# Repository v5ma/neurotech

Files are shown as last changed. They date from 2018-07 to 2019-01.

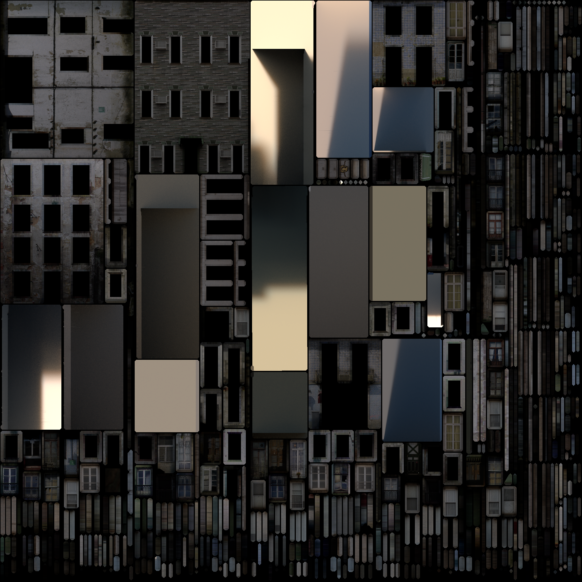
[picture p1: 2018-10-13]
brainduino-server/assets/Postwarcity/textures/TexturesCom_BuildingsTallHouse0057_S_diffuse.png

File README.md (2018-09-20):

Wiki
====

https://www.noisebridge.net/wiki/DreamTeam/Brainduinov2

Commands
========

Commands are sent by write ASCII characters to the bluetooth serial device. The brainduino echos back the lower-case compliment of the command sent 15 times followed by a return carridge. For example:

```
Client writes 'S' to bluetooth serial device
If the command is recieved by the brainduino, the brainduino writes 'sssssssssssssss' + '\r' back over bluetooth

```
ASCII | Result
---   | ---
I     | Bypass the MAX7480 (8th-order butterworth filter)
P     | Set 200HZ low-pass corner frequency of MAX7480 (8th-order butterworth filter)
O     | Set 150HZ low-pass corner frequency of MAX7480 (8th-order butterworth filter)
Q     | Set 100HZ low-pass corner frequency of MAX7480 (8th-order butterworth filter)
Z     | Set 50HZ low-pass corner frequency of MAX7480 (8th-order butterworth filter)
M     | Set 40HZ low-pass corner frequency of MAX7480 (8th-order butterworth filter)
S     | Set 32HZ low-pass corner frequency of MAX7480 (8th-order butterworth filter)
V     | Set sample rate to 500HZ
W     | Set sample rate to 250HZ
B     | Set sample rate to 190HZ
A     | Impedance check on with +1ch
T     | Impedance check on with -1ch
C     | Impedance check on with +2ch
D     | Impedance check on with -2ch
E     | Impedance check off
F     | Generate test signal with frequency = 12HZ
G     | Generate test signal with frequency = 28HZ
H     | Generate test signal with frequency = 111HZ
J     | Generate test signal with power = 0.1
K     | Generate test signal with power = 1
Y     | Set 4 channel mode
X     | Set 2 channel mode with 500HZ sample rate
U     | Set 2 channel mode with 250HZ sample rate

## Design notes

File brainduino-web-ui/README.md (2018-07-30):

On Collaboration Station
========================
In a terminal
```
$ source ~/pyvenv/brainduino/bin/activate
$ cd ~/brainduino/brainduino-web-ui
$ sudo env "PATH=$PATH" python main.py
```
Navigate to file:///home/noisebridge/brainduino/brainduino-web-ui/ws.html in a web browser. The current version of our ws.js (our simple Javascript) logs the brainduino data sent over the websocket to the browser console.

Setup
=====
* Requires Python 3.5+
* Depends on websockets and pyserial libraries

Setup for EEG reading instrument
Steps to recreate variance with 3d modeling a-frame: 
 - Connect to Bluetooth
 - run main.py
 - run web page file:///home/noisebridge/brainduino/brainduino-web-ui/webxr1.html

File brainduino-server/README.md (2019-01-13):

Operating instructions
======================

Update code
```
cd ~/go/src/github.com/Micah1/neurotech/
git pull origin master
dep ensure
```

Build and run webserver
```
cd ~/go/src/github.com/Micah1/neurotech/brainduino-server/webserver
go build
sudo ./webserver -addr 10.20.7.127:80
```

Build and run Brainduino
```
cd ~/go/src/github.com/Micah1/neurotech/brainduino-server/brainduino
go build
sudo ./brainduino -addr 10.20.7.127:80 # alternatively sudo ./brainduino --url ml.sensorium.space
```

index.html location
`~/go/src/github.com/Micah1/neurotech/brainduino-server/webserver/static/views/index.html`

load in browser
`http://10.20.7.127:80`

To commit changes to github at the end of the night
```
git add . --all
git commit -m "<what's in the commit>"
git push origin master
```

To inspect changes before committing try running `git status` or `git log`

Event Schema
============
```
type Sample struct {
        Name           string
        Channels       []float64
        Timestamp      time.Time
        SequenceNumber uint
}
Example websocket event JSON:
{
  "data": {
    "Name": "sample",
    "Channels": [0.01, 0.32],
    "Timestamp": "2018-10-10T21:05:05.031850444-07:00",
    "SequenceNumber": 1
  }
}

type FFTData struct {
        Name           string
        Channels       [][]float64
        Timestamp      time.Time
        SequenceNumber uint
}
Example websocket event JSON:
{
  "data": {
    "Name": "fft",
    "Channels": [[0.01, 0.32, ..., 0.123], [0.09234, 0.1234123, ..., 0.123543]],
    "Timestamp": "2018-10-10T21:05:05.031850444-07:00",
    "SequenceNumber": 1
  }
}
```

Online Instructions
===================
If the webserver errors out you can run sudo ifconfig to make sure the network broadcast port hasn't changed. It was once 10.20.1.164:80, and I think a new router installed at noise bridge caused it to change to 10.20.7.127

A copy of the webserver code runs on ml.sensorium.space.

For details see `./brainduino --help` or `./webserver --help`

All files in `~/go/src/github.com/Micah1/neurotech/brainduino-server/webserver/static/views` are served upon request by the brainduino-server program. For example, when the browser issues the following request `GET localhost:8080/static/index.html`, brainduino-server will serve the index.html file. `GET localhost:8080` does the same thing. `GET localhost:8080/chartsngraphs` is equivalent to `GET localhost:8080/static/chartsngraphs.html`.

For writting commands to the braindunio try `POST localhost:8080/command/S`. For a full list of brainduino commands see https://github.com/Micah1/neurotech.

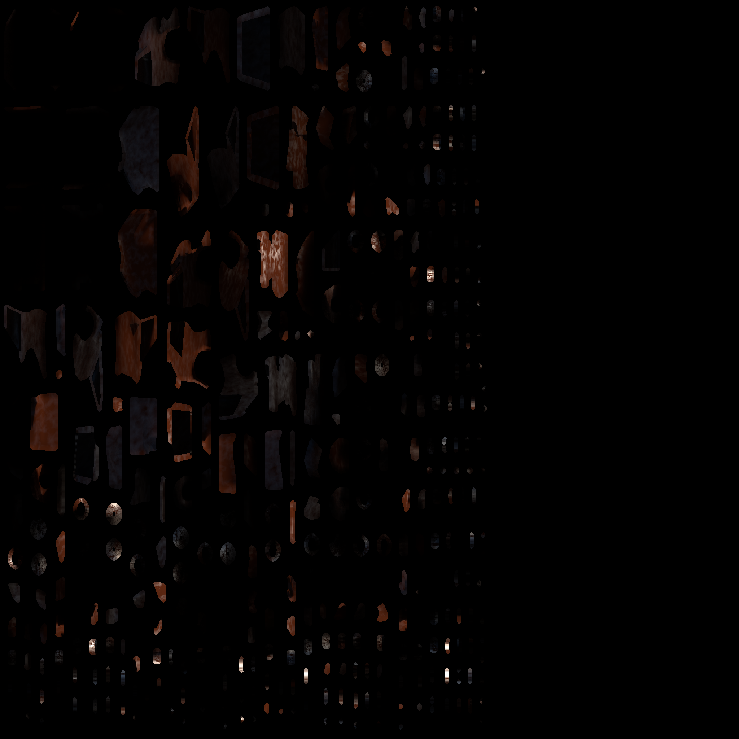
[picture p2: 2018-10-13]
brainduino-server/assets/Postwarcity/textures/jante.001_specularGlossiness.png

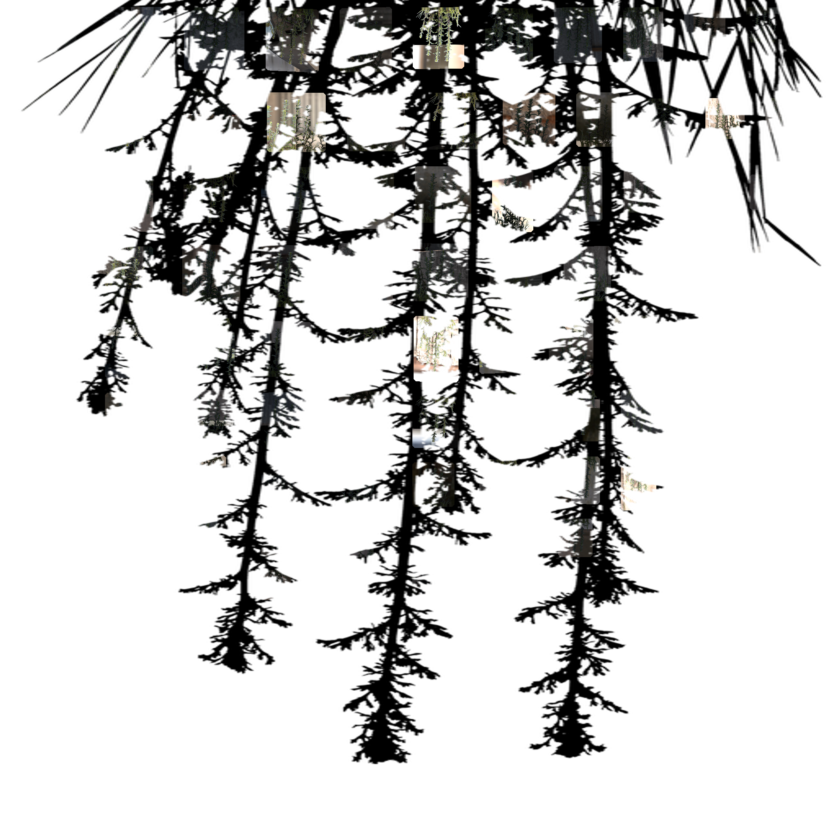
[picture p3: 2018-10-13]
brainduino-server/assets/Postwarcity/textures/TexturesCom_NaturePlants0005_1_alphamasked_S_diffuse.png

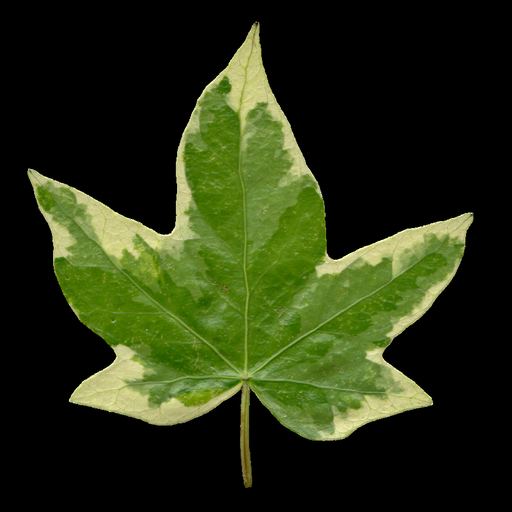
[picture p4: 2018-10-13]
brainduino-server/assets/Postwarcity/textures/ivy-leaves.001_emissive.png

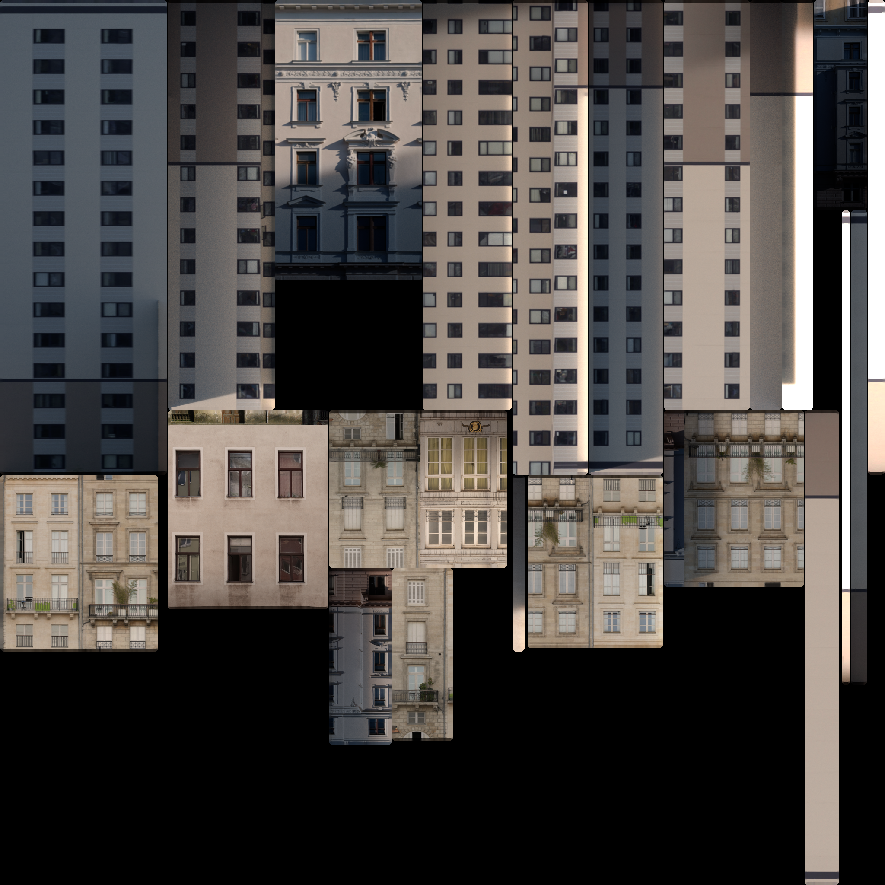
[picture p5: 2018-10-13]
brainduino-server/assets/Postwarcity/textures/wall.buidings.001_diffuse.png

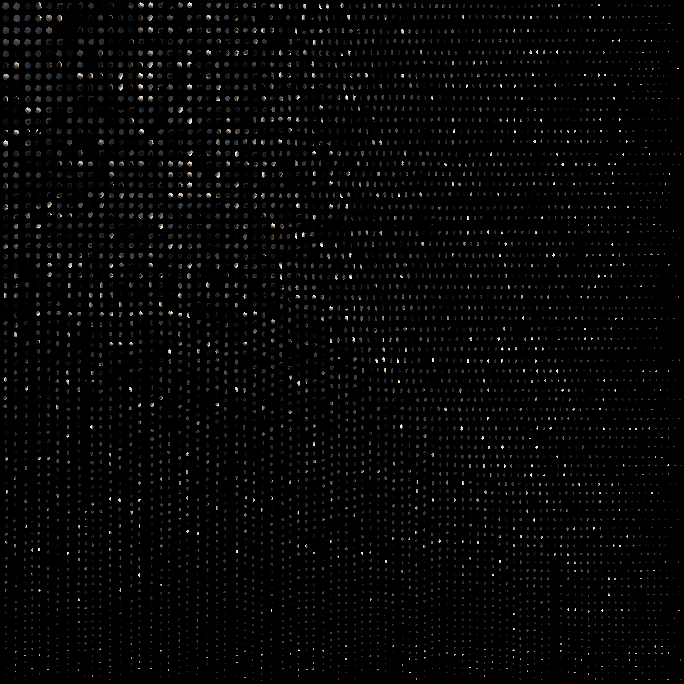
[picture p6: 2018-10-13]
brainduino-server/assets/Postwarcity/textures/gravas_diffuse.png

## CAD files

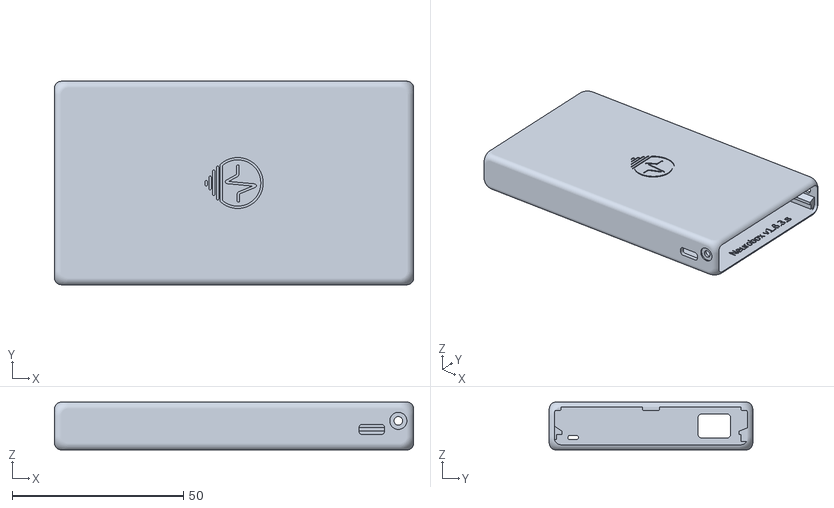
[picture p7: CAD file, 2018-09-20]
brainduino-case/Neurobox16b3s.stl
104.9 x 59.5 x 14.0

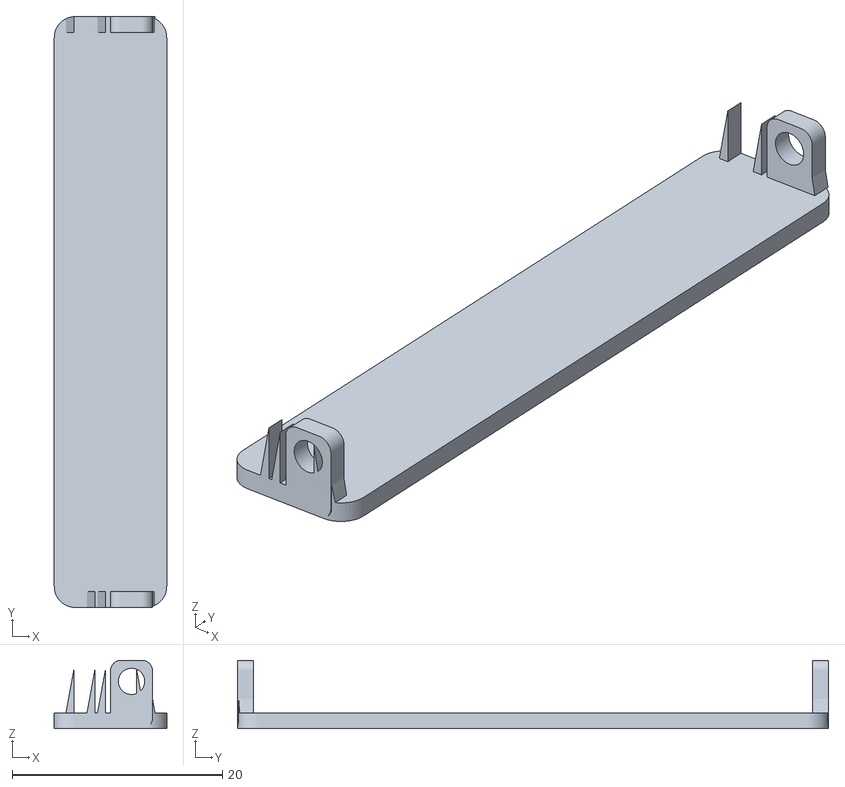
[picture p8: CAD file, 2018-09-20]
brainduino-case/Neurobox16b4s2.stl
10.7 x 56.2 x 6.50

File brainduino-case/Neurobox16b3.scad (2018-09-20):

/* [Credits] */
// www.brain-duino.com
// License CC-BY-SA 4.0
// Silver Kuusik - silver.kuusik@gmail.com

// Big thanks to:
// FB Aka Heartman/Hearty 2016
// http://www.thingiverse.com/thing:1264391

// Big thanks to:
// R. Miloh Alexander
// froggytoad@gmail.com

// Big thanks to:
// beau@nubcore.com
// 3D printing


/* [Version info] */
Version = "Neurobox v1.6.3.s";

/* [Box dimensions] */
// length, total, includes wall thickness
Length = 105;
// width, total, includes wall thickness
Width = 59.5;
// height, total includes wall thickness
Height = 14.0; // 23.5; -->> 15.5 -->> 14.0
// wall thickness
Thick = 1.5; // [2:5]

// diference 1.6 -->> 1.6.s
deltaH = 7.5; 

/* [Box options] */
// filet diameter
Filet = 2; // [0.1:12]
// filet smoothness
Resolution = 50; // [1:100]

module prism(l, w, h) {
    polyhedron(
       points=[[0,0,0], [l,0,0], [l,w,0], [0,w,0], [0,w,h], [l,w,h]],
       faces=[[0,1,2,3],[5,4,3,2],[0,4,5,1],[0,3,4],[5,2,1]]
    );
}

// round_box module
module round_box($l=Length, $w=Width, $h=Height) {
    $fn=Resolution;
    translate([0, Filet, Filet]) {
        minkowski() {
            cube([$l-(Filet/2), $w-(2*Filet), $h-(2*Filet)]);
            rotate([0, 90, 0]) {
                cylinder(r=Filet);
            }
            rotate([0, 0, 90]) {
                cylinder(r=Filet);
            }
            rotate([90, 0, 0]) {
                cylinder(r=Filet);
            }
        }
    }
} // end of round_box module

// box module
module box() {
    $fn=Resolution;
    // assemble box and it's holes
    difference() {
        // make a rounded box
        translate([Filet+2, Filet+1, Filet]) {
            round_box(Length-8, Width-5, Height-5);
        }
        // make the rounded box empty inside
        translate([Thick, Thick, Thick]) {
            translate([0, 0, 0]) {
                minkowski() {
                    cube([Length-3, Width-3, Height-3]);
                }
            }
            // make the rear opening corners round
             translate([Length-3.5, 2, 2]) {
                 minkowski() {
                    cube([1, Width-7, Height-7]);
                     rotate([0, 90, 0]) {
                        cylinder(r=Filet);
                    }
                  }
            }
        }
        // version on the rear opening
        translate([Length-3.5, Width/4, Thick-0.3]) {
            rotate([0, 0, 90]) {
                color("RoyalBlue")
                linear_extrude(0.4) {
                    text(text=Version, size=3);
                }
            }
        }
        // logo substracted from bottom part
        mirror([0, 1, 0]) {
            rotate([0, 0, -90]) {
                translate([Width/2+1, 12, 0]) {
                    logo2(0.3);
                }
            }
        }
        // logo substracted from top part
        rotate([180, 0, 0]) {
            translate([Length/2, -Width/2, -Height]) {
                rotate([0, 0, -90]) {
                    mirror([1, 0, 0]) {
                        logo(0.3);
                    }
                }
            }
        }
        // lower left lid fixation screw head hole
        translate([Length-4.5, 0.5, 8.5]) {
            rotate([90, 0, 0]) {
                cylinder(d=5);
            }
        }
        // lower left lid fixation screw hole
        translate([Length-4.5, 2, 8.5]) {
            rotate([90, 0, 0]) {
                cylinder(d=2.5, 3);
            }
        }
        /*
        // upper left lid fixation screw head hole
         translate([Length-4.5, 0.5, Height-5.5]) {
             rotate([90, 0, 0]) {
                 cylinder(d=5);
            }
         }
        // upper left lid fixation screw hole
        translate([Length-4.5, 2, Height-5.5]) {
            rotate([90, 0, 0]) {
                cylinder(d=2.5, 3);
            }
        }
        */
        /*
        // lower right lid fixation screw head hole
        translate([Length-4.5, Width+0.5, 5.5]) {
            rotate([90, 0, 0]) {
                cylinder(d=5);
            }
        }
        // lower right lid fixation screw hole
        translate([Length-4.5, Width+1, 5.5]) {
            rotate([90, 0, 0]) {
                cylinder(d=2.5, 3);
            }
        }
        */
        // upper right lid fixation screw head hole   // Height-5.5 -->> 8.5
        translate([Length-4.5, Width+0.5, 8.5]) {
            rotate([90, 0, 0]) {
                cylinder(d=5);
            }
        }
        // upper right lid fixation screw hole   // Height-5.5 -->> 8.5
        translate([Length-4.5, Width+1, 8.5]) {
            rotate([90, 0, 0]) {
                cylinder(d=2.5, 3);
            }
        }
        // DC/DC usb charging hole // Length-19.25 -->> Length-14.25 -->> 15.0
        translate([Length-15.0, 2, 5.5]) {
            rotate([90, 0, 0]) {
                minkowski() {
                    cylinder(d=Filet);
                    cube([5.5, 1, 1]);
                }
            }
        }
        // headpad hole // Width-14.3 -->> 15.0,  12.75 -->> 4.5
        translate([-0.1, Width-15.0, 4.5]) {
            minkowski() {
                cube([1, 7.5, 5]);
                rotate([0, 90, 0]) {
                    cylinder(d=Filet, 3);
                }
            }
        }
        // 200Hz LED hole  12.5 -->> 4.0 -->> 3.5
        translate([-0.1, 6, 3.5]) {
            minkowski() {
                cube([1, 2, 0.25]);
                rotate([0, 90, 0]) {
                    cylinder(d=Filet/2, 3);
                }
            }
        }
        // button hole  -->> no need for s
        /*
         translate([0.5, 3, 3.25]) {
             sphere(r=7);
         }
        // canal for button
         translate([4.25, 1, 3.5]) {
             minkowski() {
                 cube([8.5, 1, 3]);
                 rotate([90, 0, 0]) {
                    cylinder(d=Filet*2);
                }
            }
        }
        */
    } // end of difference holes
    /*difference() {
        // button support cube
        translate([1.5, 1.5, 1.5]) {
            cube([6, 9, 8.75]);
        }
        // button hole
        translate([1.49, 5, 6]) {
            //sphere(r=10);
            rotate([0, 90, 0]) {
                cylinder(d=7, 7);
            }
        }
        // button sphere
        translate([0.5, 3, 3.25]) {
            sphere(r=7);
        }
    }*/
    // left upper PCB holding rail
    translate([1.5, 1.5, 12-deltaH]) {
        cube([Length-3-20, 2.25, 1]);
        translate([0, 0, 2.5]) {
            rotate([-90, 0, 0]) {
                prism(Length-3-20, 1.5, 2.25);
            }
        }
    }
    // left middle PCB psuher
    translate([1.5, 1.5, 10.5-deltaH]) {
        cube([Length-3-20, 0.6, 1.5]);
    }
    // right upper pcb holding rail
    translate([1.5, Width-4, 12-deltaH]) {
        cube([Length-3, 3, 1]);
        translate([0, 0, 1]) {
            prism(Length-3, 2.5, 1);
        }
    }
    // right middle pcb holding rail
    translate([1.5, Width-3.5, 10-deltaH]) {
        cube([Length-3, 2, 2]);
    }
    // right lower PCB holding rail
    /*translate([1.5, Width-4, 9.25]) {
        cube([Length-3, 3, 1]);
        translate([0, 2.5, -1]) {
            rotate([90, 0, 0]) {
                prism(Length-3, 1, 2.5);
            }
        }
    }*/
    // upper middle lid support
    translate([Length-2.8, Width/2-2, Height-2]) {
        minkowski() {
            cube([0.25, 4, 1]);
            rotate([0, 90, 0]) {
                cylinder(d=1, 1);
            }
        }
        translate([0, 4, 0]) {
            rotate([90, 0, -90]) {
                minkowski() {
                    prism(4, 1, 1);
                    rotate([0, 180, 0]) {
                        cylinder(d=1, 0.01);
                    }
                }
            }
        }
    }
    // upper left lid support
    translate([Length-2.8, 2, Height-2]) {
        minkowski() {
            cube([0.25, 1, 1]);
            rotate([0, 90, 0]) {
                cylinder(d=1, 1);
            }
        }
        translate([0, 1, 0]) {
            rotate([90, 0, -90]) {
                minkowski() {
                    prism(1, 1, 1);
                    rotate([0, 180, 0]) {
                        cylinder(d=1, 0.01);
                    }
                }
            }
        }
    }
    // upper right lid support
    translate([Length-2.8, Width-3, Height-2]) {
        minkowski() {
            cube([0.25, 1, 1]);
            rotate([0, 90, 0]) {
                cylinder(d=1, 1);
            }
        }
        translate([0, 1, 0]) {
            rotate([90, 0, -90]) {
                minkowski() {
                    prism(1, 1, 1);
                    rotate([0, 180, 0]) {
                        cylinder(d=1, 0.01);
                    }
                }
            }
        }
    }
    // lower right lid support
    /*
    translate([Length-2.8, Width-3, 1]) {
        minkowski() {
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

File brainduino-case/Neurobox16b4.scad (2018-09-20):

/* [Credits] */
// www.brain-duino.com
// License CC-BY-SA 4.0
// Silver Kuusik - silver.kuusik@gmail.com

// Big thanks to:
// FB Aka Heartman/Hearty 2016
// http://www.thingiverse.com/thing:1264391

// Big thanks to:
// R. Miloh Alexander
// froggytoad@gmail.com

// Big thanks to:
// beau@nubcore.com
// 3D printing


/* [Version info] */
Version = "Neurobox v1.6.3.s";

/* [Box dimensions] */
// length, total, includes wall thickness
Length = 105;
// width, total, includes wall thickness
Width = 59.5;
// height, total includes wall thickness
Height = 14.0; // 23.5; -->> 15.5 -->> 14.0
// wall thickness
Thick = 1.5; // [2:5]

// diference 1.6 -->> 1.6.s
deltaH = 7.5; 

/* [Box options] */
// filet diameter
Filet = 2; // [0.1:12]
// filet smoothness
Resolution = 50; // [1:100]

module prism(l, w, h) {
    polyhedron(
       points=[[0,0,0], [l,0,0], [l,w,0], [0,w,0], [0,w,h], [l,w,h]],
       faces=[[0,1,2,3],[5,4,3,2],[0,4,5,1],[0,3,4],[5,2,1]]
    );
}

// round_box module
module round_box($l=Length, $w=Width, $h=Height) {
    $fn=Resolution;
    translate([0, Filet, Filet]) {
        minkowski() {
            cube([$l-(Filet/2), $w-(2*Filet), $h-(2*Filet)]);
            rotate([0, 90, 0]) {
                cylinder(r=Filet);
            }
            rotate([0, 0, 90]) {
                cylinder(r=Filet);
            }
            rotate([90, 0, 0]) {
                cylinder(r=Filet);
            }
        }
    }
} // end of round_box module

// box module
module box() {
    $fn=Resolution;
    // assemble box and it's holes
    difference() {
        // make a rounded box
        translate([Filet+2, Filet+1, Filet]) {
            round_box(Length-8, Width-5, Height-5);
        }
        // make the rounded box empty inside
        translate([Thick, Thick, Thick]) {
            translate([0, 0, 0]) {
                minkowski() {
                    cube([Length-3, Width-3, Height-3]);
                }
            }
            // make the rear opening corners round
             translate([Length-3.5, 2, 2]) {
                 minkowski() {
                    cube([1, Width-7, Height-7]);
                     rotate([0, 90, 0]) {
                        cylinder(r=Filet);
                    }
                  }
            }
        }
        // version on the rear opening
        translate([Length-3.5, Width/4, Thick-0.3]) {
            rotate([0, 0, 90]) {
                color("RoyalBlue")
                linear_extrude(0.4) {
                    text(text=Version, size=3);
                }
            }
        }
        // logo substracted from bottom part
        mirror([0, 1, 0]) {
            rotate([0, 0, -90]) {
                translate([Width/2+1, 12, 0]) {
                    logo2(0.3);
                }
            }
        }
        // logo substracted from top part
        rotate([180, 0, 0]) {
            translate([Length/2, -Width/2, -Height]) {
                rotate([0, 0, -90]) {
                    mirror([1, 0, 0]) {
                        logo(0.3);
                    }
                }
            }
        }
        // lower left lid fixation screw head hole
        translate([Length-4.5, 0.5, 8.5]) {
            rotate([90, 0, 0]) {
                cylinder(d=5);
            }
        }
        // lower left lid fixation screw hole
        translate([Length-4.5, 2, 8.5]) {
            rotate([90, 0, 0]) {
                cylinder(d=2.5, 3);
            }
        }
        /*
        // upper left lid fixation screw head hole
         translate([Length-4.5, 0.5, Height-5.5]) {
             rotate([90, 0, 0]) {
                 cylinder(d=5);
            }
         }
        // upper left lid fixation screw hole
        translate([Length-4.5, 2, Height-5.5]) {
            rotate([90, 0, 0]) {
                cylinder(d=2.5, 3);
            }
        }
        */
        /*
        // lower right lid fixation screw head hole
        translate([Length-4.5, Width+0.5, 5.5]) {
            rotate([90, 0, 0]) {
                cylinder(d=5);
            }
        }
        // lower right lid fixation screw hole
        translate([Length-4.5, Width+1, 5.5]) {
            rotate([90, 0, 0]) {
                cylinder(d=2.5, 3);
            }
        }
        */
        // upper right lid fixation screw head hole   // Height-5.5 -->> 8.5
        translate([Length-4.5, Width+0.5, 8.5]) {
            rotate([90, 0, 0]) {
                cylinder(d=5);
            }
        }
        // upper right lid fixation screw hole   // Height-5.5 -->> 8.5
        translate([Length-4.5, Width+1, 8.5]) {
            rotate([90, 0, 0]) {
                cylinder(d=2.5, 3);
            }
        }
        // DC/DC usb charging hole // Length-19.25 -->> Length-14.25 -->> 15.0
        translate([Length-15.0, 2, 5.5]) {
            rotate([90, 0, 0]) {
                minkowski() {
                    cylinder(d=Filet);
                    cube([5.5, 1, 1]);
                }
            }
        }
        // headpad hole // Width-14.3 -->> 15.0,  12.75 -->> 4.5
        translate([-0.1, Width-15.0, 4.5]) {
            minkowski() {
                cube([1, 7.5, 5]);
                rotate([0, 90, 0]) {
                    cylinder(d=Filet, 3);
                }
            }
        }
        // 200Hz LED hole  12.5 -->> 4.0 -->> 3.5
        translate([-0.1, 6, 3.5]) {
            minkowski() {
                cube([1, 2, 0.25]);
                rotate([0, 90, 0]) {
                    cylinder(d=Filet/2, 3);
                }
            }
        }
        // button hole  -->> no need for s
        /*
         translate([0.5, 3, 3.25]) {
             sphere(r=7);
         }
        // canal for button
         translate([4.25, 1, 3.5]) {
             minkowski() {
                 cube([8.5, 1, 3]);
                 rotate([90, 0, 0]) {
                    cylinder(d=Filet*2);
                }
            }
        }
        */
    } // end of difference holes
    /*difference() {
        // button support cube
        translate([1.5, 1.5, 1.5]) {
            cube([6, 9, 8.75]);
        }
        // button hole
        translate([1.49, 5, 6]) {
            //sphere(r=10);
            rotate([0, 90, 0]) {
                cylinder(d=7, 7);
            }
        }
        // button sphere
        translate([0.5, 3, 3.25]) {
            sphere(r=7);
        }
    }*/
    // left upper PCB holding rail
    translate([1.5, 1.5, 12-deltaH]) {
        cube([Length-3-20, 2.25, 1]);
        translate([0, 0, 2.5]) {
            rotate([-90, 0, 0]) {
                prism(Length-3-20, 1.5, 2.25);
            }
        }
    }
    // left middle PCB psuher
    translate([1.5, 1.5, 10.5-deltaH]) {
        cube([Length-3-20, 0.6, 1.5]);
    }
    // right upper pcb holding rail
    translate([1.5, Width-4, 12-deltaH]) {
        cube([Length-3, 3, 1]);
        translate([0, 0, 1]) {
            prism(Length-3, 2.5, 1);
        }
    }
    // right middle pcb holding rail
    translate([1.5, Width-3.5, 10-deltaH]) {
        cube([Length-3, 2, 2]);
    }
    // right lower PCB holding rail
    /*translate([1.5, Width-4, 9.25]) {
        cube([Length-3, 3, 1]);
        translate([0, 2.5, -1]) {
            rotate([90, 0, 0]) {
                prism(Length-3, 1, 2.5);
            }
        }
    }*/
    // upper middle lid support
    translate([Length-2.8, Width/2-2, Height-2]) {
        minkowski() {
            cube([0.25, 4, 1]);
            rotate([0, 90, 0]) {
                cylinder(d=1, 1);
            }
        }
        translate([0, 4, 0]) {
            rotate([90, 0, -90]) {
                minkowski() {
                    prism(4, 1, 1);
                    rotate([0, 180, 0]) {
                        cylinder(d=1, 0.01);
                    }
                }
            }
        }
    }
    // upper left lid support
    translate([Length-2.8, 2, Height-2]) {
        minkowski() {
            cube([0.25, 1, 1]);
            rotate([0, 90, 0]) {
                cylinder(d=1, 1);
            }
        }
        translate([0, 1, 0]) {
            rotate([90, 0, -90]) {
                minkowski() {
                    prism(1, 1, 1);
                    rotate([0, 180, 0]) {
                        cylinder(d=1, 0.01);
                    }
                }
            }
        }
    }
    // upper right lid support
    translate([Length-2.8, Width-3, Height-2]) {
        minkowski() {
            cube([0.25, 1, 1]);
            rotate([0, 90, 0]) {
                cylinder(d=1, 1);
            }
        }
        translate([0, 1, 0]) {
            rotate([90, 0, -90]) {
                minkowski() {
                    prism(1, 1, 1);
                    rotate([0, 180, 0]) {
                        cylinder(d=1, 0.01);
                    }
                }
            }
        }
    }
    // lower right lid support
    /*
    translate([Length-2.8, Width-3, 1]) {
        minkowski() {
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

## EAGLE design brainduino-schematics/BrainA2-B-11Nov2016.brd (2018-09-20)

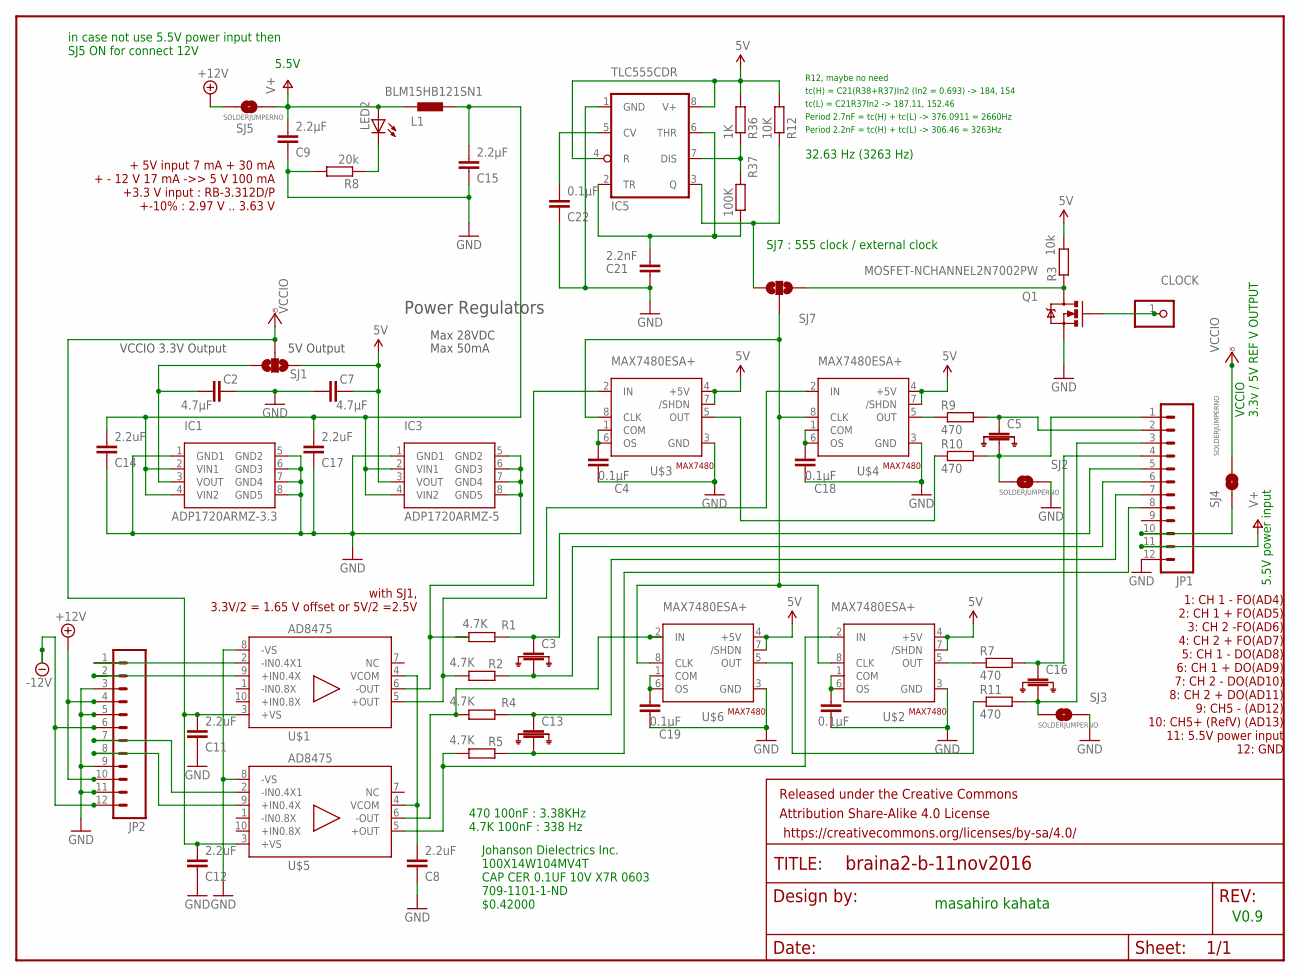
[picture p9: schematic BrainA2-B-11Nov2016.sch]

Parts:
C1, C4, C18, C19: 0.1µF; 0402-CAP
C2, C7: 4.7µF; 0402-CAP
C3, C5, C13, C16: C-EUX2Y; C0603
C8, C11, C12, C14, C17: 2.2uF; C0402
C9, C15: 2.2µF; 0402-CAP
C21: 2.2nF; C0402
C22: 0.1µF; C0402
CLOCK: PINHD-1X1; 1X01
FRAME1: FRAME-LETTER; CREATIVE_COMMONS
IC1: ADP1720ARMZ-3.3; MSOP08
IC3: ADP1720ARMZ-5; MSOP08
IC5: TLC555CDR; SO08
JP1, JP2: M12NO_SILK; 1X12_NO_SILK
L1: BLM15HB121SN1; 0402
LED2: LEDCHIP-LED0603; CHIP-LED0603
Q1: MOSFET-NCHANNEL2N7002PW; SOT323
R1, R2, R4, R5: 4.7K; R0402
R3: 10k; R0402
R7, R9, R10, R11: 470; R0402
R8: 20k; R0402
R12: 10K; R0402
R36: 1K; R0402
R37: 100K; R0402
SJ1, SJ7: SOLDERJUMPER_2WAYS; SJ_3
SJ2, SJ3, SJ4, SJ5: SOLDERJUMPERNO; SJ_2S-NO
U$1, U$5: AD8475; MSOP10
U$2, U$3, U$4, U$6: MAX7480ESA+; MAX7480

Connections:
5V: C7.1, IC3.3 (VOUT), IC5.4 (R), IC5.8 (V+), R3.2, R12.2, R36.2, SJ1.1, U$2.4 (+5V), U$2.7 (/SHDN), U$3.4 (+5V), U$3.7 (/SHDN), U$4.4 (+5V), U$4.7 (/SHDN), U$6.4 (+5V), U$6.7 (/SHDN)
+12V: JP2.4, JP2.10, SJ5.1
-12V: JP2.6, JP2.12
GND: C1.1, C2.1, C3.GND, C4.1, C5.GND, C7.2, C8.1, C9.1, C11.1, C12.1, C13.GND, C14.1, C15.1, C16.GND, C17.1, C18.1, C19.1, C21.1, C22.1, IC1.1 (GND1), IC1.5 (GND2), IC1.6 (GND3), IC1.7 (GND4), IC1.8 (GND5), IC3.1 (GND1), IC3.5 (GND2), IC3.6 (GND3), IC3.7 (GND4), IC3.8 (GND5), IC5.1 (GND), JP1.12, JP2.3, JP2.5, JP2.9, JP2.11, Q1.2 (S), R8.2, SJ2.2, SJ3.2, U$1.8 (-VS), U$2.3 (GND), U$3.3 (GND), U$4.3 (GND), U$5.8 (-VS), U$6.3 (GND)
unnamed: C13.2, JP1.8, R5.2
unnamed: C1.2, U$2.1 (COM), U$2.6 (OS)
unnamed: R11.1, U$6.5 (OUT)
unnamed: JP2.1, U$1.2 (-IN0.4X1)
unnamed: R7.1, U$2.5 (OUT)
unnamed: JP2.2, U$1.9 (+IN0.4X)
unnamed: C3.2, JP1.6, R2.2
unnamed: C3.1, JP1.5, R1.2
unnamed: C5.2, JP1.1, R10.2, SJ2.1
unnamed: R2.1, U$1.5 (+OUT), U$4.2 (IN)
unnamed: C4.2, U$3.1 (COM), U$3.6 (OS)
unnamed: Q1.3 (D), R3.1, SJ7.3
unnamed: JP1.10, SJ4.1
unnamed: R10.1, U$3.5 (OUT)
unnamed: C8.2, U$1.4 (VCOM), U$5.4 (VCOM)
unnamed: LED2.C, R8.1
unnamed: R4.1, U$5.6 (-OUT), U$6.2 (IN)
unnamed: JP2.8, U$5.9 (+IN0.4X)
unnamed: C13.1, JP1.7, R4.2
unnamed: JP2.7, U$5.2 (-IN0.4X1)
unnamed: C5.1, JP1.2, R9.2
unnamed: C18.2, U$4.1 (COM), U$4.6 (OS)
unnamed: C14.2, C15.2, C17.2, IC1.2 (VIN1), IC1.4 (VIN2), IC3.2 (VIN1), IC3.4 (VIN2), L1.2
unnamed: R9.1, U$4.5 (OUT)
unnamed: CLOCK.1, Q1.1 (G)
unnamed: R5.1, U$2.2 (IN), U$5.5 (+OUT)
unnamed: R1.1, U$1.6 (-OUT), U$3.2 (IN)
unnamed: IC5.3 (Q), R12.1, SJ7.1
unnamed: C16.1, JP1.4, R7.2
unnamed: C2.2, IC1.3 (VOUT), SJ1.3
unnamed: C16.2, JP1.3, R11.2, SJ3.1
unnamed: C19.2, U$6.1 (COM), U$6.6 (OS)
unnamed: SJ7.2, U$2.8 (CLK), U$3.8 (CLK), U$4.8 (CLK), U$6.8 (CLK)
unnamed: IC5.7 (DIS), R36.1, R37.2
unnamed: C21.2, IC5.2 (TR), IC5.6 (THR), R37.1
unnamed: C22.2, IC5.5 (CV)
V+: C9.2, JP1.11, L1.1, LED2.A, SJ5.2
VCCIO: C11.2, C12.2, SJ1.2, SJ4.2, U$1.3 (+VS), U$5.3 (+VS)

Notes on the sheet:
+ 5V input 7 mA + 30 mA + - 12 V 17 mA ->> 5 V 100 mA +3.3 V input : RB-3.312D/P +-10% : 2.97 V .. 3.63 V
masahiro kahata
1: CH 1 - FO(AD4) 2: CH 1 + FO(AD5) 3: CH 2 -FO(AD6) 4: CH 2 + FO(AD7) 5: CH 1 - DO(AD8) 6: CH 1 + DO(AD9) 7: CH 2 - DO(AD10) 8: CH 2 + DO(AD11) 9: CH5 - (AD12) 10: CH5+ (RefV) (AD13) 11: 5.5V power input 12: GND
with SJ1, 3.3V/2 = 1.65 V offset or 5V/2 =2.5V
VCCIO 3.3v / 5V REF V OUTPUT
32.63 Hz (3263 Hz)
SJ7 : 555 clock / external clock
5.5V power input
470 100nF : 3.38KHz 4.7K 100nF : 338 Hz
Johanson Dielectrics Inc. 100X14W104MV4T CAP CER 0.1UF 10V X7R 0603 709-1101-1-ND $0.42000
V0.9
Power Regulators
VCCIO 3.3V Output
5V Output
Max 50mA
Max 28VDC
R12, maybe no need
tc(H) = C21(R38+R37)In2 (In2 = 0.693) -> 184, 154
tc(L) = C21R37In2 -> 187.11, 152.46
Period 2.7nF = tc(H) + tc(L) -> 376.0911 = 2660Hz
Period 2.2nF = tc(H) + tc(L) -> 306.46 = 3263Hz
5.5V
in case not use 5.5V power input then SJ5 ON for connect 12V

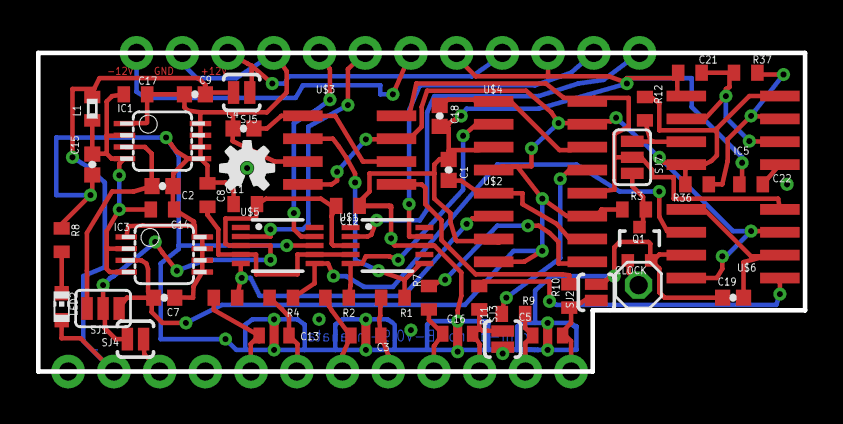
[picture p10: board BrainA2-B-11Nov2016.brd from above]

Board: 2 copper layers, 42.6 x 17.7 mm, 55 parts (0 on the bottom side), 42 nets.

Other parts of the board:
U$8: OSHW-LOGO-S

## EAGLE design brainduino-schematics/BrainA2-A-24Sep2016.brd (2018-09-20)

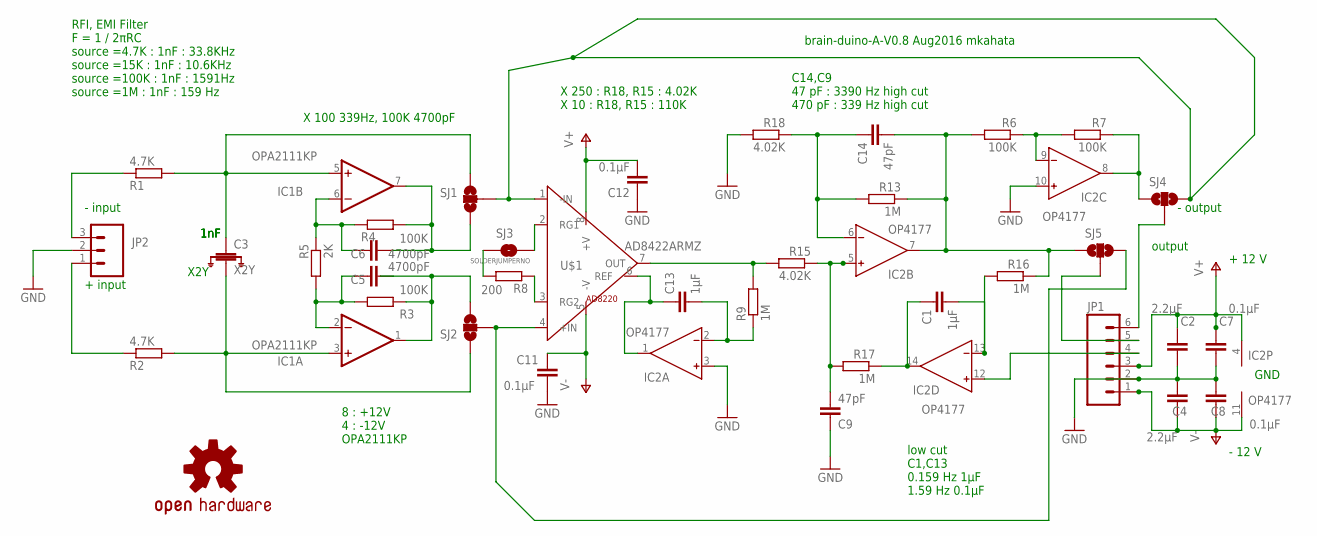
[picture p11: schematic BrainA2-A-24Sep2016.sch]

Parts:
C1, C13: 1µF; C0402
C2, C4: 2.2µF; C0402
C3: X2Y; C0603
C5, C6: 4700pF; C0402
C7, C8, C11, C12: 0.1µF; C0402
C9, C14: 47pF; C0402
IC1: OPA2111KP; DIL08
IC2: OP4177; TSSOP14
JP1: M06SILK_FEMALE_PTH; 1X06
JP2: M03PTH; 1X03
LOGO1: OSHW-LOGOS; OSHW-LOGO-S
R1, R2: 4.7K; R0402
R3, R4, R6, R7: 100K; R0402
R5: 2K; R0402
R8: 200; R0402
R9, R13, R16, R17: 1M; R0402
R15, R18: 4.02K; R0402
SJ1, SJ2, SJ4, SJ5: SOLDERJUMPER_2WAYPASTE2&3; SJ_3_PASTE2&3
SJ3: SOLDERJUMPERNO; SJ_2S-NO
U$1: AD8422ARMZ; AD8220

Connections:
GND: C2.1, C3.GND, C4.2, C7.1, C8.2, C9.1, C11.2, C12.1, IC2.3 (IN+), IC2.10 (IN+), JP1.2, JP2.2, R18.2
unnamed: JP2.3, R1.1
unnamed: R8.2, SJ3.1
unnamed: JP2.1, R2.1
unnamed: C3.2, IC1.3 (+IN), R2.2, SJ2.1
unnamed: C3.1, IC1.5 (+IN), R1.2, SJ1.1
unnamed: IC2.9 (IN-), R6.1, R7.2
unnamed: C5.1, IC1.2 (-IN), R3.1, R5.2
unnamed: C6.1, IC1.6 (-IN), R4.1, R5.1
unnamed: SJ1.2, SJ4.1, U$1.1 (-IN)
unnamed: SJ2.2, SJ5.1, U$1.4 (+IN)
unnamed: C5.2, IC1.1 (OUT), R3.2, SJ2.3
unnamed: C6.2, IC1.7 (OUT), R4.2, SJ1.3
unnamed: R8.1, U$1.3 (RG2)
unnamed: JP1.6, SJ4.2
unnamed: C1.2, IC2.13 (IN-), R16.2
unnamed: SJ3.2, U$1.2 (RG1)
unnamed: C9.2, IC2.5 (IN+), R15.1, R17.2
unnamed: R9.2, R15.2, U$1.7 (OUT)
unnamed: C13.2, IC2.2 (IN-), R9.1
unnamed: C14.2, IC2.7 (OUT), R6.2, R13.1, R16.1, SJ5.3
unnamed: C13.1, IC2.1 (OUT), U$1.6 (REF)
unnamed: C14.1, IC2.6 (IN-), R13.2, R18.1
unnamed: IC2.12 (IN+), JP1.4
unnamed: C1.1, IC2.14 (OUT), R17.1
unnamed: IC2.8 (OUT), R7.1, SJ4.3
unnamed: JP1.5, SJ5.2
V+: C2.2, C7.2, C12.2, IC1.8 (V+), IC2.4 (V+), JP1.3, U$1.8 (+V)
V-: C4.1, C8.1, C11.1, IC1.4 (V-), IC2.11 (V-), JP1.1, U$1.5 (-V)

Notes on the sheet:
+ 12 V
- 12 V
GND
brain-duino-A-V0.8 Aug2016 mkahata
X2Y
output
- output
8 : +12V 4 : -12V OPA2111KP
+ input
- input
1nF
X 100 339Hz, 100K 4700pF
X 250 : R18, R15 : 4.02K X 10 : R18, R15 : 110K
RFI, EMI Filter F = 1 / 2πRC source =4.7K : 1nF : 33.8KHz source =15K : 1nF : 10.6KHz source =100K : 1nF : 1591Hz source =1M : 1nF : 159 Hz
low cut C1,C13 0.159 Hz 1µF 1.59 Hz 0.1µF
C14,C9 47 pF : 3390 Hz high cut 470 pF : 339 Hz high cut

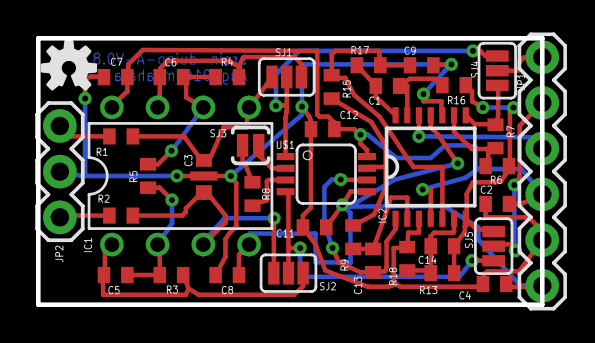
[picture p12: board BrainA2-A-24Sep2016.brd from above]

Board: 2 copper layers, 28.0 x 14.8 mm, 38 parts (0 on the bottom side), 29 nets.

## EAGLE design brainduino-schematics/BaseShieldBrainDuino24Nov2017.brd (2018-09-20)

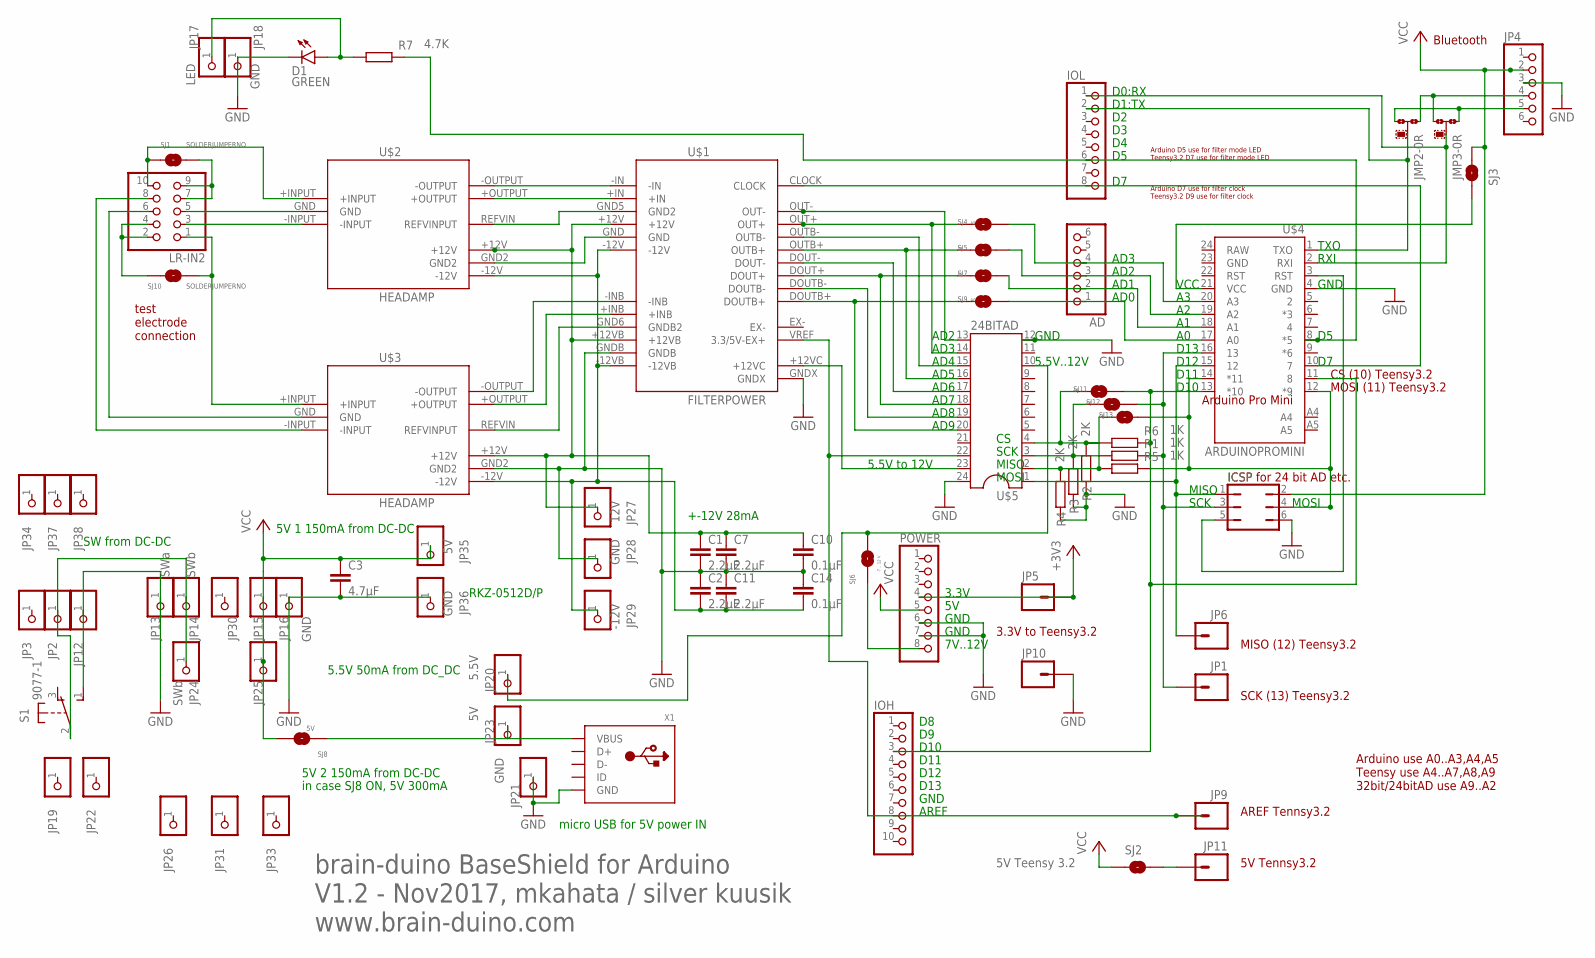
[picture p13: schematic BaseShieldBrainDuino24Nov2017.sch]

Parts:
AD: PINHD-1X6; 1X06
C1, C2, C7, C11: 2.2µF; C0402
C3: 4.7µF; C0402
C10, C14: 0.1µF; C0402
D1: GREEN; LED-0603
ICSP: JP3Q
IOH: PINHD-1X10; 1X10
IOL: PINHD-1X8; 1X08
JMP2: RX; A0R-JMP
JMP3: TX; A0R-JMP
JP1, JP5, JP6, JP9, JP10, JP11: M01PTH; 1X01
JP2, JP3, JP12, JP19, JP22, JP26, JP30, JP31, JP33, JP34, JP37, JP38: PINHD-1X1; 1X01
JP4: PINHD-1X6; 1X06
JP13: SWa; 1X01
JP14, JP24: SWb; 1X01
JP15, JP25: +5V; 1X01
JP16, JP18, JP21, JP28, JP36: GND; 1X01
JP17: LED; 1X01
JP20: 5.5V; 1X01
JP23, JP35: 5V; 1X01
JP27: 12V; 1X01
JP29: -12V; 1X01
LR-IN2: PINHD-2X5/90; 2X05/90
POWER: PINHD-1X8; 1X08
R1, R5, R6: 1K; R0402
R2, R3, R4: 2K; R0402
R7: 4.7K; R0402
S1: 9077-1
SJ1, SJ10: SOLDERJUMPERNO; SJ_2S-NO
SJ2: 5V Teensy 3.2; SJ_2S-NO
SJ3: 5V Arduino Pro Mini; SJ_2S-NO
SJ4: A5; SJ_2S-NO
SJ5, SJ11, SJ12, SJ13: A4; SJ_2S-NO
SJ6: 7 .. 12 V; SJ_2S-NO
SJ7: A2; SJ_2S-NO
SJ8: 5V; SJ_2S-NO
SJ9: A0; SJ_2S-NO
U$1: FILTERPOWER
U$2, U$3: HEADAMP
U$4: ARDUINOPROMINI
U$5: 24BITAD
X1: USB_MICRO_20329_V2; 4UCONN_20329_V2

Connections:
+3V3: JP5.1, POWER.4
+12VB: C1.1, C7.1, C10.1, JP27.1, U$1.+12V, U$1.+12VB, U$2.+12V, U$3.+12V
-12V: C2.2, C11.2, C14.2, JP29.1, U$1.-12V, U$1.-12VB, U$2.-12V, U$3.-12V
GND: C1.2, C2.1, C3.2, C7.2, C10.2, C11.1, C14.1, D1.C, ICSP.6, JP4.3, JP10.1, JP12.1, JP13.1, JP16.1, JP18.1, JP21.1, JP28.1, JP36.1, POWER.6, POWER.7, R2.1, R3.1, R4.1, S1.1 (S), U$1.GNDB, U$1.GNDX, U$3.GND2, U$4.4 (GND), U$5.12, U$5.24, X1.BASE@1 (GND), X1.BASE@2 (GND), X1.GND, X1.SPRT@1 (GND), X1.SPRT@2 (GND), X1.SPRT@3 (GND), X1.SPRT@4 (GND)
unnamed: SJ3.1, U$4.21 (VCC)
unnamed: U$1.GND, U$2.GND2
unnamed: JP2.1, JP14.1, JP24.1, S1.2
unnamed: POWER.8, SJ6.1
unnamed: ICSP.3, JP1.1, R1.2, SJ12.2, U$4.16 (13)
unnamed: LR-IN2.8, U$3.-INPUT
unnamed: JP23.1, SJ8.1, X1.VBUS
unnamed: U$1.GND6 (GNDB2), U$3.REFVIN (REFVINPUT)
unnamed: U$1.-INB, U$3.-OUTPUT
unnamed: U$1.+INB, U$3.+OUTPUT
unnamed: LR-IN2.3, U$2.-INPUT
unnamed: U$1.OUTB-, U$5.15
unnamed: U$1.+12VC, U$5.23
unnamed: U$1.OUT-, U$5.13
unnamed: JMP2.1, JMP3.3, JP4.4
unnamed: IOL.8, U$1.CLOCK, U$4.10 (7)
unnamed: ICSP.1, JP6.1, U$4.15 (12), U$5.1
unnamed: IOL.2, JMP2.2, U$4.1 (TXO)
unnamed: U$1.-IN, U$2.-OUTPUT
unnamed: IOL.1, JMP3.2, U$4.2 (RXI)
unnamed: IOH.3, R6.2, SJ11.2, U$4.11 (8), U$4.13 (*10)
unnamed: AD.2, SJ7.2, U$4.18 (A1)
unnamed: AD.1, SJ9.2, U$4.17 (A0)
unnamed: ICSP.4, R5.2, SJ13.2, U$4.12 (*9), U$4.14 (*11)
unnamed: JMP2.3, JMP3.1, JP4.5
unnamed: SJ9.1, U$1.DOUTB+, U$5.20
unnamed: JP11.1, SJ2.2
unnamed: JP20.1, SJ6.2, U$5.10
unnamed: U$1.DOUTB-, U$5.19
unnamed: U$1.+IN, U$2.+OUTPUT
unnamed: SJ7.1, U$1.DOUT+, U$5.18
unnamed: U$1.DOUT-, U$5.17
unnamed: IOH.8, JP9.1, U$1.VREF (3.3/5V-EX+), U$5.22
unnamed: AD.4, SJ4.2, U$4.20 (A3)
unnamed: SJ4.1, U$1.OUT+, U$5.14
unnamed: SJ5.1, U$1.OUTB+, U$5.16
unnamed: LR-IN2.1, SJ10.2, U$3.+INPUT
unnamed: LR-IN2.10, SJ1.1, U$2.+INPUT
unnamed: LR-IN2.7, LR-IN2.9, SJ1.2
unnamed: LR-IN2.2, LR-IN2.4, SJ10.1
unnamed: R2.2, R6.1, SJ11.1, U$5.4
unnamed: R1.1, R3.2, SJ12.1, U$5.3
unnamed: R4.2, R5.1, SJ13.1, U$5.2
unnamed: AD.3, SJ5.2, U$4.19 (A2)
unnamed: U$1.GND5 (GND2), U$2.REFVIN (REFVINPUT)
unnamed: LR-IN2.6, U$3.GND
unnamed: ICSP.5, U$4.3 (RST)
unnamed: D1.A, JP17.1, R7.1
unnamed: IOL.6, R7.2, U$4.8 (*5)
unnamed: LR-IN2.5, U$2.GND
VCC: C3.1, ICSP.2, JP4.2, JP15.1, JP25.1, JP35.1, POWER.5, SJ2.1, SJ3.2, SJ8.2

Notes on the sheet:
D0:RX
D1:TX
D13
D12
AREF
GND
AD0
AD1
AD2
AD3
7V..12V
D10
D11
test electrode connection
MOSI (11) Teensy3.2
brain-duino BaseShield for Arduino V1.2 - Nov2017, mkahata / silver kuusik www.brain-duino.com
Bluetooth
MOSI
MISO
SCK
3.3V to Teensy3.2
SCK (13) Teensy3.2
MISO (12) Teensy3.2
ICSP for 24 bit AD etc.
CS (10) Teensy3.2
Arduino use A0..A3,A4,A5 Teensy use A4..A7,A8,A9 32bit/24bitAD use A9..A2
5V Tennsy3.2
Arduino D7 use for filter clock Teensy3.2 D9 use for filter clock
3.3V
AD9
AD8
AD7
AD6
AD5
AD4
5.5V..12V
AREF Tennsy3.2
TXO
RXI
VCC

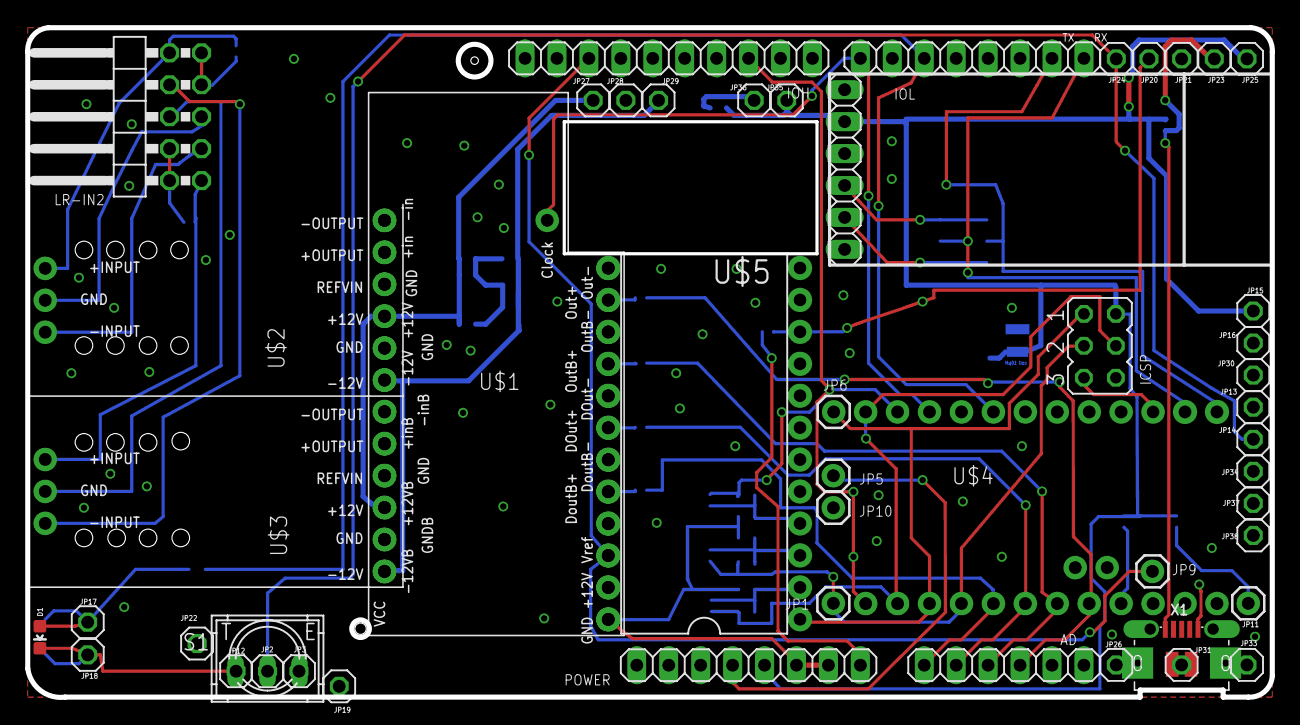
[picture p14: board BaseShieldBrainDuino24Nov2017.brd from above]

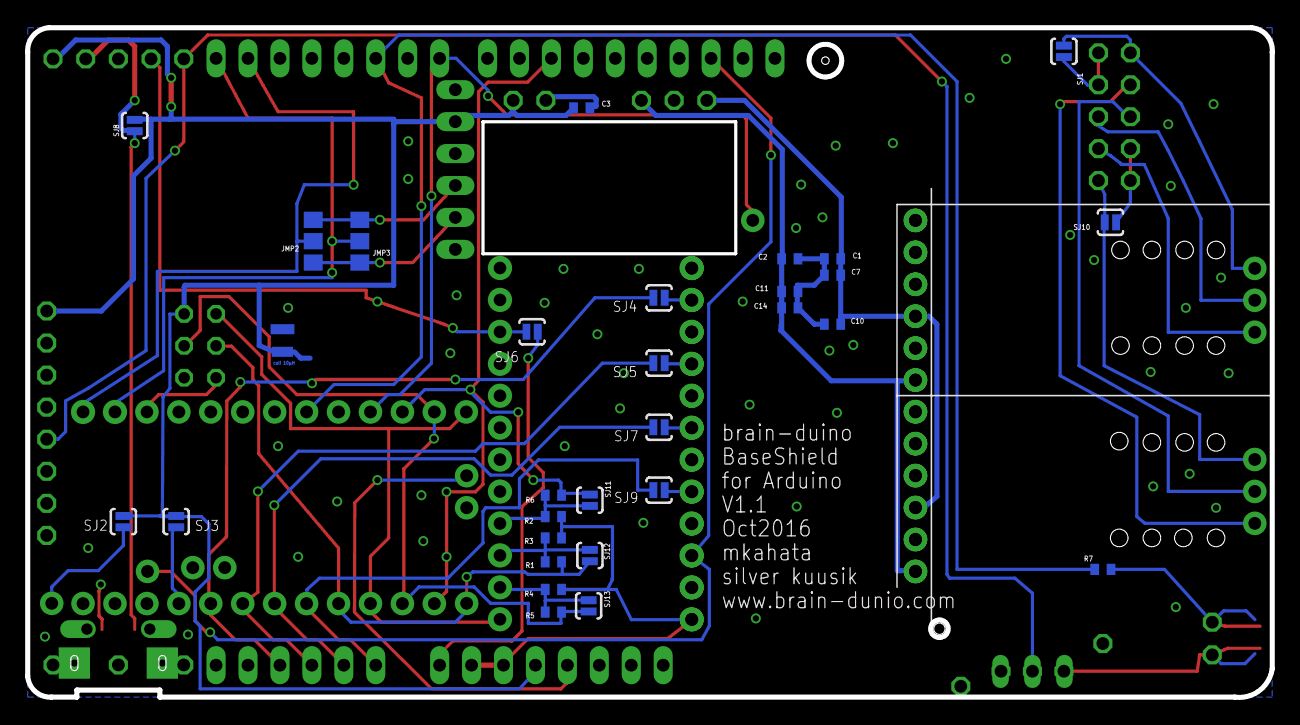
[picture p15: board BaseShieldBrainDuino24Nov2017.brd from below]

Board: 2 copper layers, 99.0 x 53.3 mm, 78 parts (29 on the bottom side), 55 nets.

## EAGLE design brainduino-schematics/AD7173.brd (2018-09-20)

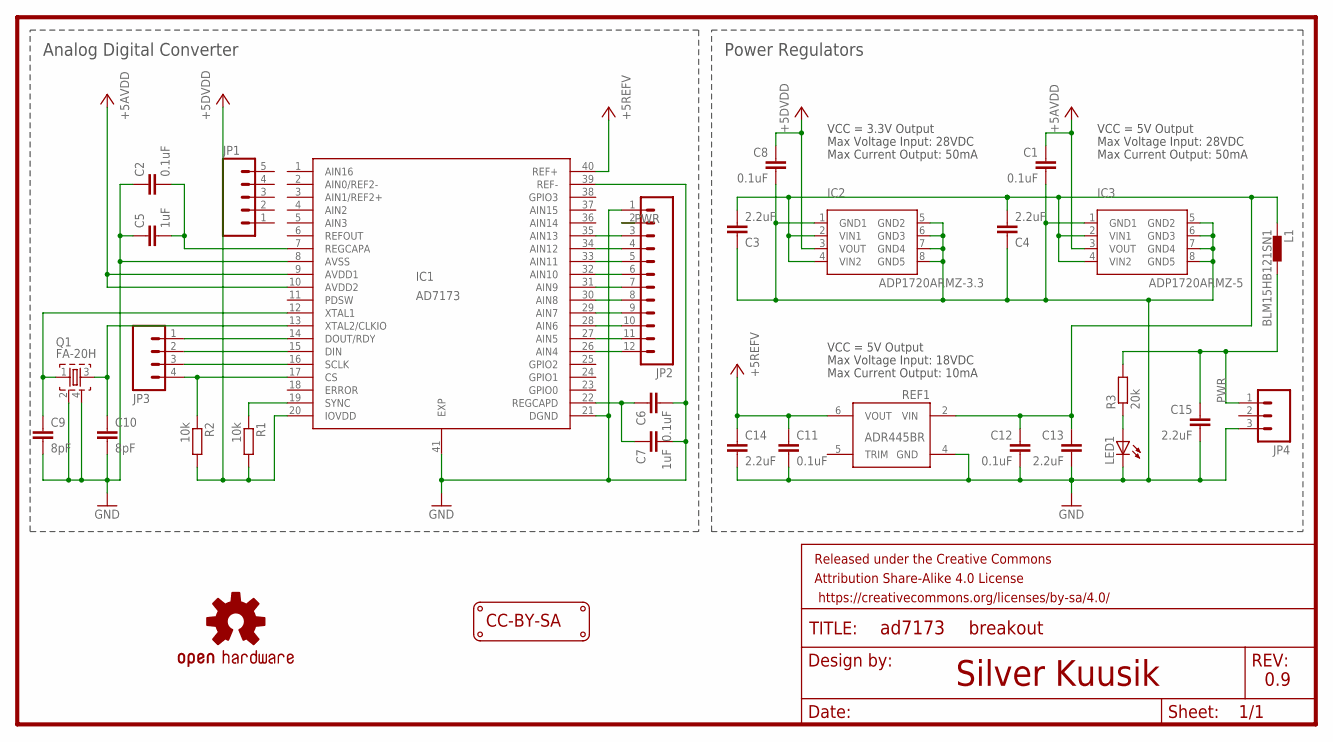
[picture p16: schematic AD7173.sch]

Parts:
C1, C2, C6, C8, C11, C12: 0.1uF; C0402
C3, C4, C13, C14, C15: 2.2uF; C0402
C5, C7: 1uF; C0402
C9, C10: 8pF; C0402
FRAME1: FRAME-LETTER; CREATIVE_COMMONS
IC1: AD7173; LFCSP_WQ6X6MM
IC2: ADP1720ARMZ-3.3; MSOP08
IC3: ADP1720ARMZ-5; MSOP08
JP1: M05PTH; 1X05
JP2: M12PTH; 1X12
JP3: M04PTH; 1X04
JP4: M03PTH; 1X03
L1: BLM15HB121SN1; 0402
LED1: LEDCHIP-LED0603; CHIP-LED0603
LOGO1: OSHW-LOGOS; OSHW-LOGO-S
LOGO2: LOGO_CC-BY-SA
Q1: FA-20H
R1, R2: 10k; R0402
R3: 20k; R0402
REF1: ADR445BR; SO8

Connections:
+3V3: C8.1, IC1.20 (IOVDD), IC2.3 (VOUT), R1.2, R2.2
+5V: C1.1, IC1.9 (AVDD1), IC1.10 (AVDD2), IC3.3 (VOUT)
GND: C1.2, C2.1, C3.1, C4.1, C5.1, C6.2, C7.2, C8.2, C9.2, C10.2, C11.2, C12.2, C13.2, C14.2, C15.2, IC1.8 (AVSS), IC1.21 (DGND), IC1.39 (REF-), IC1.41 (EXP), IC2.1 (GND1), IC2.5 (GND2), IC2.6 (GND3), IC2.7 (GND4), IC2.8 (GND5), IC3.1 (GND1), IC3.5 (GND2), IC3.6 (GND3), IC3.7 (GND4), IC3.8 (GND5), JP2.1, JP4.3, LED1.C, Q1.2, Q1.4, REF1.4 (GND)
unnamed: IC1.16 (SCLK), JP3.3
unnamed: IC1.17 (CS), JP3.4, R2.1
unnamed: C6.1, C7.1, IC1.22 (REGCAPD)
unnamed: IC1.34 (AIN12), JP2.4
unnamed: C2.2, C5.2, IC1.7 (REGCAPA)
unnamed: IC1.35 (AIN13), JP2.3
unnamed: IC1.33 (AIN11), JP2.5
unnamed: IC1.32 (AIN10), JP2.6
unnamed: IC1.31 (AIN9), JP2.7
unnamed: IC1.30 (AIN8), JP2.8
unnamed: IC1.29 (AIN7), JP2.9
unnamed: IC1.15 (DIN), JP3.2
unnamed: IC1.27 (AIN5), JP2.11
unnamed: IC1.26 (AIN4), JP2.12
unnamed: C10.1, IC1.13 (XTAL2/CLKIO), Q1.3
unnamed: IC1.28 (AIN6), JP2.10
unnamed: IC1.14 (DOUT/RDY), JP3.1
unnamed: C9.1, IC1.12 (XTAL1), Q1.1
unnamed: LED1.A, R3.1
unnamed: IC1.19 (SYNC), R1.1
PWR: C15.1, JP2.2, JP4.1, L1.2, R3.2
VCC: C11.1, C14.1, IC1.40 (REF+), REF1.6 (VOUT)
VIN: C3.2, C4.2, C12.1, C13.1, IC2.2 (VIN1), IC2.4 (VIN2), IC3.2 (VIN1), IC3.4 (VIN2), L1.1, REF1.2 (VIN)

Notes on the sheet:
Power Regulators
Analog Digital Converter
VCC = 3.3V Output
Max Current Output: 50mA
Max Voltage Input: 28VDC
VCC = 5V Output
Max Voltage Input: 18VDC
Max Current Output: 10mA
Silver Kuusik
breakout
0.9

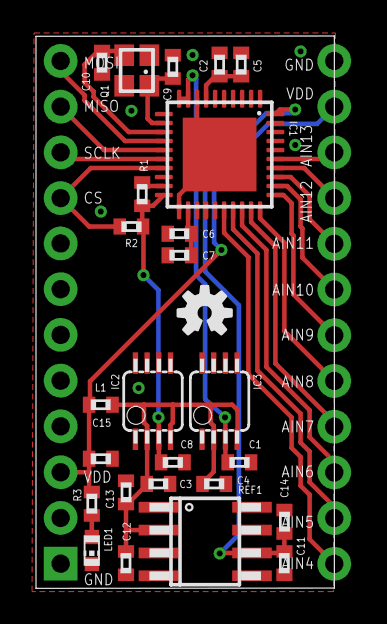
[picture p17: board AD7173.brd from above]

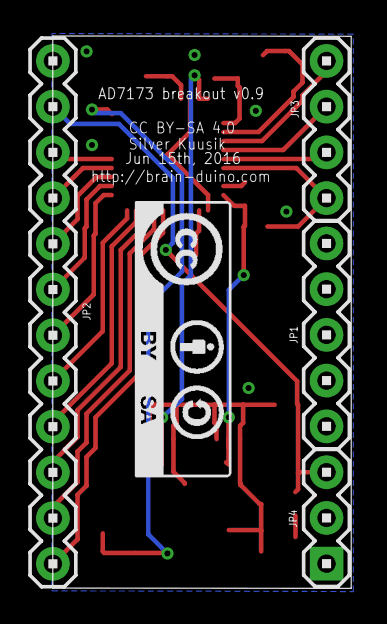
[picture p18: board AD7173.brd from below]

Board: 2 copper layers, 16.6 x 30.7 mm, 32 parts (5 on the bottom side), 26 nets.

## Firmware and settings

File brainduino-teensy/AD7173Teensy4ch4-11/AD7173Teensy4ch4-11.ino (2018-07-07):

// Teensy 24bit 2ch (4ch) brain-duino with filter frequency control LED
// In Arduino IDE select Tools > Board > Teensy 3.1/3.2

#include <SPI.h>
#include <AD7173.h>
#include <Arduino.h>
#include <Audio.h>
#include <Wire.h>

#define HWSERIAL Serial1

AudioSynthWaveformSine sine1;
AudioOutputAnalog dac1;
AudioConnection patchCord2 (sine1, dac1);

long freq = 12;			// 18000 is not good shape, 1000 is nice, use for test impedance 12Hz
unsigned long baud = 19200;
unsigned long baud1 = 230400;	// 460800

const int ledPin = 9;		// 13 // use for clock
const byte chipselect = 10;

// Create an IntervalTimer object 
IntervalTimer myTimer;
IntervalTimer myTimer1;

const int analogInPin = 4;	// Analog input pin A0 -->> A4
const int analogInPin2 = 5;	// Analog input pin A1 -->> A5
const int analogInPin3 = 6;	// Analog input pin A2 -->> A6
const int analogInPin4 = 7;	// Analog input pin A3 -->> A7

int sensorValue = 0;		// value read from the pot
int outputValue = 0;		// value output to the PWM (analog out)
int sensorValue2 = 0;		// value read from the pot
int outputValue2 = 0;		// value output to the PWM (analog out)
int sensorValue3 = 0;		// value read from the pot
int outputValue3 = 0;		// value output to the PWM (analog out)
int sensorValue4 = 0;		// value read from the pot
int outputValue4 = 0;		// value output to the PWM (analog out)
int sensorValue5 = 0;		// value read from the pot
int outputValue5 = 0;		// value output to the PWM (analog out)
int sensorValue6 = 0;		// value read from the pot
int outputValue6 = 0;		// value output to the PWM (analog out)

String channel1 = "abc";
String channel2 = "abc";
String channel3 = "abc";
String channel4 = "abc";
String channel5 = "abc";
String channel6 = "abc";
String zeroChar = "0";

byte buffer[20];
String stringOne;

int ledON;
int ledON2;

const int ledPin2 = 7;		// Teensy // 6 : Arduino // use for LED SW : filter mode, ON is use filter ( 30Hz, 40Hz, 50Hz , 100, 150Hz 200Hz )
const int ledPin4 = 4;		// Teensy . // 2 : Arduino
const int ledPin5 = 5;		// Teensy . // 3 : Arduino
const int ledPin6 = 6;		// Teensy . // 4 : Arduino
const int ledPin7 = 8;		// Teensy . // 5 : Arduino

String txtMsg = "";
boolean stringComplete = false;	// whether the string is complete
String inputString = "";

byte valueR[1];

int InputX = 0;
float sineP = 0.1;
long data;
int data1, data2, data3, data4;
int countD;
int dataX;
byte value0[3];
byte value1[3];
byte value2[3];
byte value3[3];
byte value4[3];
long loopcount;
long MaxCount;

// 2 = 2 channel system, 4 = 4 channel system
int Nchannel = 2;

// final DC offset Calibration, 1 = 0.5 µV

// NeurofoxKeid
// long CH0offset = -3254; // -4254
// long CH1offset = 2937; // 3837

// Libertas
long CH0offset = 3500; // 4,794
long CH1offset = -6000; // -7742

// NeurofoxArcturus
// long CH0offset = -10000;	// -13,895
// long CH1offset = 11000;		// 14527

// NeurofoxCursa
// long CH0offset = 4700; // 6,016
// long CH1offset = 6000; // 8560

long CH2offset = 0;
long CH3offset = 0;
long CH4offset = 0;

// Function definitions here:
void setupInput (int);
void setupAD7173 ();
void setupMyTimer (int);
void setupMyTimer1 (int);
void setupInputX (int);
void HEXprint (byte);
void HEXprint24bit (byte, byte, byte, byte, byte, byte);
void SimpleHEXprint24bit (byte, byte, byte, byte, byte, byte);
void HEXprint24bit4ch (byte, byte, byte, byte, byte, byte, byte, byte, byte, byte, byte, byte);
void HEXprint24bit5ch (byte, byte, byte, byte, byte, byte, byte, byte, byte, byte, byte, byte, byte, byte, byte);
void sendData (int);
void getData ();
void callbackX ();
void callback ();
void setupSampleF (int);
void impedanceCheck (int);

void setup ()
{

  pinMode (ledPin, OUTPUT);
  pinMode (ledPin2, OUTPUT);

  pinMode (ledPin4, OUTPUT);
  pinMode (ledPin5, OUTPUT);
  pinMode (ledPin6, OUTPUT);
  pinMode (ledPin7, OUTPUT);


  // this is for Teensy 3.2 : 72 MHz

  myTimer.begin (callback, 25);	// blinkLED to run 39965.625 Hz
  myTimer.priority (0);

  Serial.begin (baud);		// USB, communication to PC or Mac
  HWSERIAL.begin (baud1);	// communication to hardware serial

  // 29 July 2015
  //     analogReference(EXTERNAL);

  pinMode (chipselect, OUTPUT);
  digitalWrite (chipselect, LOW);

  delay (200);

  // setup for direct mode
  setupAD7173 ();


  /* wait for ADC */
  delay (200);

  // set as filter mode
  setupInput (0);		// 1:direct mode, not use filter, 0 filter


  digitalWrite (ledPin2, LOW);	// direct mode, not use filter

  // set OFF
  impedanceCheck (4);

}

void setupInput (int maxF)
{

  InputX = maxF;

  // 0 is filter, 1 is direct
  if (Nchannel == 2) {
    if (InputX == 1) {
      AD7173.set_channel_config (CH0, true, SETUP2, AIN8, AIN9);
      AD7173.set_channel_config (CH1, true, SETUP3, AIN10, AIN11);

      AD7173.set_setup_config (SETUP2, BIPOLAR);
      AD7173.set_setup_config (SETUP3, BIPOLAR);

      AD7173.set_offset_config (OFFSET2, CH2offset);
      AD7173.set_offset_config (OFFSET3, CH3offset);
    }
  else if (InputX == 0) {
    AD7173.set_channel_config (CH0, true, SETUP0, AIN4, AIN5);
    AD7173.set_channel_config (CH1, true, SETUP1, AIN6, AIN7);

    AD7173.set_setup_config (SETUP0, BIPOLAR);
    AD7173.set_setup_config (SETUP1, BIPOLAR);

    AD7173.set_offset_config (OFFSET0, CH0offset);
    AD7173.set_offset_config (OFFSET1, CH1offset);
    }
  }
  countD = 0;
}

void setupAD7173 ()
{
  /* initiate ADC, return true if device ID is valid */
  AD7173.init ();
  AD7173.sync ();
  /* reset ADC registers to the default state */
  AD7173.reset ();
  AD7173.sync ();

  /* check if the ID register of the ADC is valid */
  if (AD7173.is_valid_id ())
    Serial.println ("AD7173 ID is valid");
  else
    Serial.println ("AD7173 ID is invalid");


  /* set ADC input channel configuration */
  /* enable channel 0 and channel 1 and connect each to 2 analog inputs for bipolar input */
  /* CH0 - CH15 */
  /* true/false to enable/disable channel */
  /* SETUP0 - SETUP7 */
  /* AIN0 - AIN16 */


// setup for 2channle 24bit
//
  if (Nchannel == 2) {
    if (InputX == 1) {
      AD7173.set_channel_config (CH0, true, SETUP2, AIN8, AIN9);
      AD7173.set_channel_config (CH1, true, SETUP3, AIN10, AIN11);

      AD7173.set_setup_config (SETUP2, BIPOLAR);
      AD7173.set_setup_config (SETUP3, BIPOLAR);

      AD7173.set_offset_config (OFFSET2, CH2offset);
      AD7173.set_offset_config (OFFSET3, CH3offset);
    } else if (InputX == 0) {
	  AD7173.set_channel_config (CH0, true, SETUP0, AIN4, AIN5);
	  AD7173.set_channel_config (CH1, true, SETUP1, AIN6, AIN7);

	  AD7173.set_setup_config (SETUP0, BIPOLAR);
	  AD7173.set_setup_config (SETUP1, BIPOLAR);

	  AD7173.set_offset_config (OFFSET0, CH0offset);
	  AD7173.set_offset_config (OFFSET1, CH1offset);
    }
  }

// setup for 4channle 24bit
  else if (Nchannel == 4) {
    AD7173.set_channel_config (CH0, true, SETUP0, AIN4, AIN5);
    AD7173.set_channel_config (CH1, true, SETUP1, AIN6, AIN7);
    AD7173.set_channel_config (CH2, true, SETUP2, AIN8, AIN9);
    AD7173.set_channel_config (CH3, true, SETUP3, AIN10, AIN11);

    AD7173.set_setup_config (SETUP0, BIPOLAR);
    AD7173.set_setup_config (SETUP1, BIPOLAR);
    AD7173.set_setup_config (SETUP2, BIPOLAR);
    AD7173.set_setup_config (SETUP3, BIPOLAR);

    AD7173.set_offset_config (OFFSET0, CH0offset);
    AD7173.set_offset_config (OFFSET1, CH1offset);
    AD7173.set_offset_config (OFFSET2, CH2offset);
    AD7173.set_offset_config (OFFSET3, CH3offset);
  } else if (Nchannel == 5) {
    AD7173.set_channel_config (CH0, true, SETUP0, AIN4, AIN5);
    AD7173.set_channel_config (CH1, true, SETUP1, AIN6, AIN7);
    AD7173.set_channel_config (CH2, true, SETUP2, AIN8, AIN9);
    AD7173.set_channel_config (CH3, true, SETUP3, AIN10, AIN11);
    AD7173.set_channel_config (CH4, true, SETUP4, AIN12, AIN13);

    AD7173.set_setup_config (SETUP0, BIPOLAR);
    AD7173.set_setup_config (SETUP1, BIPOLAR);
    AD7173.set_setup_config (SETUP2, BIPOLAR);
    AD7173.set_setup_config (SETUP3, BIPOLAR);
    AD7173.set_setup_config (SETUP4, BIPOLAR);

    AD7173.set_offset_config (OFFSET0, CH0offset);
    AD7173.set_offset_config (OFFSET1, CH1offset);
    AD7173.set_offset_config (OFFSET2, CH2offset);
    AD7173.set_offset_config (OFFSET3, CH3offset);
    AD7173.set_offset_config (OFFSET4, CH4offset);
  }
  /*
     set the ADC SETUP0 coding mode to BIPLOAR output
     SETUP0 - SETUP7
     BIPOLAR, UNIPOLAR

     set ADC OFFSET0 offset value
     OFFSET0 - OFFSET7
    
     this function put gain setup with offset setup
     this Gain0 setup is for only one AD7173 : somethings Gain is strange.
     ->> AD7173.set_gain_config(GAIN0, 32768);
     byte valueX[3] = {0x00, 0x80, 0x00}; -->> 32768
     {0x00, 0x50, 0x00}; -->> 20480
     byte valueX[3] = {0x50, 0x00, 0x00}; -->> 5242880 --=> reset
     byte valueX[3] = {0x55, 0x55, 0x55}; -->> 5592405 --=> nominal
     {0x10, 0x00, 0x00}; -->> 1048576
     {0x01, 0x00, 0x00}; -->> 65536
     use this need modify 3 files : AD7173.h AD7173.cpp keywords.txt
    


     SPS_1007 2ch makes 500 Hz sampling par channel
     SPS_1007 4ch makes 250 Hz sampling par channel
     SPS_2597 need to use external Bluetooth deveice
     SPS_2597 2ch makes 1300 Hz sampling par channel
     SPS_2597 4ch makes 650 Hz sampling par channel

     set the ADC FILTER0 ac_rejection to false and samplingrate to 1007 Hz
     FILTER0 - FILTER7
     SPS_1, SPS_2, SPS_5, SPS_10, SPS_16, SPS_20, SPS_49, SPS_59, SPS_100, SPS_200
     SPS_381, SPS_503, SPS_1007, SPS_2597, SPS_5208, SPS_10417, SPS_15625, SPS_31250
  */

  if ((Nchannel == 4) || (Nchannel == 5)) {
      AD7173.set_filter_config (FILTER0, SPS_1007);
      AD7173.set_filter_config (FILTER1, SPS_1007);
      AD7173.set_filter_config (FILTER2, SPS_1007);
      AD7173.set_filter_config (FILTER3, SPS_1007);
      AD7173.set_filter_config (FILTER4, SPS_1007);
  } else {
      AD7173.set_filter_config (FILTER0, SPS_503);
      AD7173.set_filter_config (FILTER1, SPS_503);
      AD7173.set_filter_config (FILTER2, SPS_503);
      AD7173.set_filter_config (FILTER3, SPS_503);
      AD7173.set_filter_config (FILTER4, SPS_503);
  }

  /* 
     Set the ADC data and clock mode
     CONTINUOUS_CONVERSION_MODE, SINGLE_CONVERSION_MODE
     in SINGLE_CONVERSION_MODE after all setup channels are sampled the ADC goes into STANDBY_MODE
     to exit STANDBY_MODE use this same function to go into CONTINUOUS or SINGLE_CONVERSION_MODE
     INTERNAL_CLOCK, INTERNAL_CLOCK_OUTPUT, EXTERNAL_CLOCK_INPUT, EXTERNAL_CRYSTAL
     ex clock : 10min9sec, int clock : 10min7sec when set 500 Hz 10min
    
  */
  // AD7173.set_adc_mode_config(CONTINUOUS_CONVERSION_MODE, INTERNAL_CLOCK);
  AD7173.set_adc_mode_config (CONTINUOUS_CONVERSION_MODE, EXTERNAL_CRYSTAL);


  // enable or disable CONTINUOUS_READ_MODE, to exit use AD7173.reset(); */
  // AD7173.reset(); return all registers to default state, so everything has to be setup again */
  AD7173.set_interface_mode_config (false);

}


/*
Set up high-cut frequency
*/
void setupMyTimer (int speedA)
{
  myTimer.end ();
  myTimer.begin (callback, speedA);
  myTimer.priority (0);
}

/*
Set up LED blink speed -- high-cut frequency indicator
*/
void setupMyTimer1 (int speedA)
{
  ledON2 = 0;
  myTimer1.end ();
  myTimer1.begin (callbackX, speedA);
}

/*
Sets high-cut frequency + LED blink frequency based on cases below
*/
void setupInputX (int maxF)
{
  switch (maxF) {
    case 0:
      setupInput (0);
      setupMyTimer (160);	//  run 6270 -> 3134.8 Hz -->> 32Hz
      setupMyTimer1 (450000);
      break;
    case 1:
      setupInput (0);
      setupMyTimer (25);	//  run 39965.625 Hz -> 20000 -->> 200Hz
      setupMyTimer1 (16000);
      break;
    case 2:
      setupInput (0);
      setupMyTimer (33);	//  run 30000Hz -> 15000 -->> 150Hz
      setupMyTimer1 (33000);
      break;
    case 3:
      setupInput (0);
      setupMyTimer (50);	//   run 20000 -> 10000 -->> 100Hz
      setupMyTimer1 (50000);
      break;
    case 4:
      setupInput (0);
      setupMyTimer (100);	//   run 10000 -> 5000 -->> 50Hz
      setupMyTimer1 (100000);
      break;
    case 5:
      setupInput (0);
      setupMyTimer (128);	//   blinkLED  to run 8000 -> 4000 -->> 40Hz
      setupMyTimer1 (200000);
      break;
    case 6:
      setupInput (1);		// direct mode
      setupMyTimer (25);	//  run 39965.625 Hz -> 20000 -->> 200Hz
      myTimer1.end ();
      ledON2 = 2;
      digitalWrite (ledPin2, LOW);
      break;
    default:
      ledON2 = 2;
  }
}


/*
Ensure 2 ASCII characters are always printed
inval <= 00001000 print leading 0 for most significant four bits
*/
void HEXprint (byte inVal)
{
  if (inVal >= 16) {
    HWSERIAL.print (inVal, HEX);
  } else {
    HWSERIAL.print (0);
    HWSERIAL.print (inVal, HEX);
  }
}

/*
Protocol explained:
- Each channel has 24bits of information
- A hex value is 4bits
- Send 12bits (1.5bytes) with tab-delimiter followed by 12bits (1.5bytes)
|--------- Channel 1 --------|--------- Channel 2 --------|
Hex-Hex-Hex	Hex-Hex-Hex	Hex-Hex-Hex	Hex-Hex-Hex
- Encoding from ADC is offset binary where K = 2^23 gives a dynamic range of  -8388608 (all off) to 8322607 (all on)
- Each channel is converted to 2 tab-delimited, ASCII-Hex encoded, 12bit words to be interpreted as a continuous 24bit offset binary word
*/
void HEXprint24bit (byte inVal1, byte inVal2, byte inVal3, byte inVal4, byte inVal5, byte inVal6)
{
  HEXprint (inVal1);
  if (inVal2 >= 16) {
    HWSERIAL.print (inVal2 / 16, HEX); // 4 most significant bits
    HWSERIAL.write (0x09);
    HWSERIAL.print (inVal2 - ((inVal2 / 16) * 16), HEX); // 4 least significant bits
  } else {
    HWSERIAL.print (0);
    HWSERIAL.write (0x09);
    HWSERIAL.print (inVal2, HEX);
  }
  HEXprint (inVal3);

  HWSERIAL.write (0x09);

  HEXprint (inVal4);
  /*
  if (inVal4 >= 16) {
    HWSERIAL.print (inVal4, HEX);
  } else {
    HWSERIAL.print (0);
    HWSERIAL.print (inVal4, HEX);
  }
  */
  if (inVal5 >= 16) {
    HWSERIAL.print (inVal5 / 16, HEX);
    HWSERIAL.write (0x09);
    HWSERIAL.print (inVal5 - ((inVal5 / 16) * 16), HEX);
  } else {
    HWSERIAL.print (0);
    HWSERIAL.write (0x09);
    HWSERIAL.print (inVal5, HEX);
  }
  HEXprint (inVal6);
}

void SimpleHEXprint24bit (byte inVal1, byte inVal2, byte inVal3, byte inVal4, byte inVal5, byte inVal6)
{
  HEXprint (inVal1);
  HEXprint (inVal2);
  HEXprint (inVal3);
  HWSERIAL.write(0x09);
  HEXprint (inVal4);
  HEXprint (inVal5);
  HEXprint (inVal6);
}

void HEXprint24bit4ch (byte inVal1, byte inVal2, byte inVal3, byte inVal4,
		  byte inVal5, byte inVal6, byte inVal7, byte inVal8,
		  byte inVal9, byte inVal10, byte inVal11, byte inVal12)
{
  byte outStream[16];

  outStream[0] = inVal1;
  outStream[1] = inVal2;
  outStream[2] = inVal3;

  outStream[3] = inVal4;
  outStream[4] = inVal5;
  outStream[5] = inVal6;

  outStream[6] = inVal7;
  outStream[7] = inVal8;
  outStream[8] = inVal9;

  outStream[9] = inVal10;
  outStream[10] = inVal11;
  outStream[11] = inVal12;

  // time stamp, etc.
  outStream[12] = 0x55;
  outStream[13] = 0x44;
  outStream[14] = 0x33;

  outStream[15] = 0x0D;		// return

  HWSERIAL.write (outStream, 16);
}


void HEXprint24bit5ch (byte inVal1, byte inVal2, byte inVal3, byte inVal4,
		  byte inVal5, byte inVal6, byte inVal7, byte inVal8,
		  byte inVal9, byte inVal10, byte inVal11, byte inVal12,
		  byte inVal13, byte inVal14, byte inVal15)
{
  byte outStream[16];

  outStream[0] = inVal1;
  outStream[1] = inVal2;
  outStream[2] = inVal3;

  outStream[3] = inVal4;
  outStream[4] = inVal5;
  outStream[5] = inVal6;

  outStream[6] = inVal7;
  outStream[7] = inVal8;
  outStream[8] = inVal9;

  outStream[9] = inVal10;
  outStream[10] = inVal11;
  outStream[11] = inVal12;

  outStream[12] = inVal13;
  outStream[13] = inVal14;
  outStream[14] = inVal15;

  outStream[15] = 0x0D;		// return

  HWSERIAL.write (outStream, 16);
}
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
void loop ()
{
  char inChar = '0';

  getData ();

  if (HWSERIAL.available ()) {
    // get the new byte:
    inChar = (char) HWSERIAL.read ();

    // if the incoming character is a newline, set a flag
    // so the main loop can do something about it:

    // B is problem (-CH1 ) -->> T

    if ((inChar == 'S') || (inChar == 'I') || (inChar == 'P')
	|| (inChar == 'O') || (inChar == 'Q') || (inChar == 'Z')
	|| (inChar == 'M') || (inChar == 'V') || (inChar == 'W')
	|| (inChar == 'A') || (inChar == 'T') || (inChar == 'C')
	|| (inChar == 'D') || (inChar == 'E') || (inChar == 'F')
	|| (inChar == 'G') || (inChar == 'H') || (inChar == 'J')
	|| (inChar == 'K') || (inChar == 'X') || (inChar == 'Y')
	|| (inChar == 'U') || (inChar == 'B')) {
      stringComplete = true;
      Serial.println ("command input ");
    }

  }

  // print the message and a notice if it's changed:
  if (stringComplete)
    {

      switch (inChar)
	{
	case 'S':
	  // 32 Hz cut // in IBVA :0

	  HWSERIAL.print ("sssssssssssssss");
	  HWSERIAL.print ("\r");
	  //   Serial.println( "sssssssssssssss" );
	  setupInputX (0);	// fiter frequency : 0 is 32Hz
	  break;
	case 'I':
	  // direct : go down from 200, 300, 400, 500, 600 // in IBVA :6

	  HWSERIAL.print ("iiiiiiiiiiiiiii");
	  HWSERIAL.print ("\r");
	  //     Serial.println( "iiiiiiiiiiiiiii" );
	  setupInputX (6);	// fiter frequency : 1 is 200Hz 
	  break;
	case 'P':
	  // 200 Hz cut // in IBVA :5

	  HWSERIAL.print ("ppppppppppppppp");
	  HWSERIAL.print ("\r");
	  //   Serial.println( "ppppppppppppppp" );
	  setupInputX (1);	// fiter frequency : 1 is 200Hz
	  break;
	case 'O':
	  // 150 Hz cut // in IBVA :4

	  HWSERIAL.print ("ooooooooooooooo");
	  HWSERIAL.print ("\r");
	  //      Serial.println( "ooooooooooooooo" );
	  setupInputX (2);	// fiter frequency : 2 is 150Hz
	  break;
	case 'Q':
	  // 100 Hz cut // in IBVA :3

	  HWSERIAL.print ("qqqqqqqqqqqqqqq");
	  HWSERIAL.print ("\r");
	  //    Serial.println( "qqqqqqqqqqqqqqq" );
	  setupInputX (3);	// fiter frequency : 3 is 100Hz
	  break;
	case 'Z':
	  // 50 Hz cut // in IBVA :2

	  HWSERIAL.print ("zzzzzzzzzzzzzzz");
	  HWSERIAL.print ("\r");
	  //    Serial.println( "zzzzzzzzzzzzzzz" );
	  setupInputX (4);	// fiter frequency : 4 is 50Hz     
	  break;
	case 'M':
	  // 40 Hz cut // in IBVA :1

	  HWSERIAL.print ("mmmmmmmmmmmmmmm");
	  HWSERIAL.print ("\r");
	  //    Serial.println( "mmmmmmmmmmmmmmm" );
	  setupInputX (5);	// fiter frequency : 5 is 40Hz
	  break;
	case 'V':
	  // setup 500 Hz sampling
	  setupSampleF (0);

	  HWSERIAL.print ("vvvvvvvvvvvvvvv");
	  HWSERIAL.print ("\r");
	  //   Serial.println( "vvvvvvvvvvvvvvv" );

	  break;
	case 'W':
	  // setup 1.3 KHz sampling  -->> 250 Hz
	  setupSampleF (1);

	  HWSERIAL.print ("wwwwwwwwwwwwwww");
	  HWSERIAL.print ("\r");
	  //   Serial.println( "wwwwwwwwwwwwwww" );

	  break;
	case 'B':
	  // setup 1.3 KHz sampling  -->> 250 Hz
	  setupSampleF (2);

	  HWSERIAL.print ("bbbbbbbbbbbbbbb");
	  HWSERIAL.print ("\r");
	  //   Serial.println( "bbbbbbbbbbbbbbb" );

	  break;
	case 'A':
	  // setup impedance check +1ch

	  HWSERIAL.print ("aaaaaaaaaaaaaaa");
	  HWSERIAL.print ("\r");
	  //   Serial.println( "aaaaaaaaaaaaaaa" );
	  impedanceCheck (0);
	  break;
	case 'T':
	  // setup impedance check -1ch

	  HWSERIAL.print ("ttttttttttttttt");
	  HWSERIAL.print ("\r");
	  //   Serial.println( "ttttttttttttttt" );
	  impedanceCheck (1);
	  break;
	case 'C':
	  // setup impedance check +2ch

	  HWSERIAL.print ("ccccccccccccccc");
	  HWSERIAL.print ("\r");
	  //   Serial.println( "ccccccccccccccc" );
	  impedanceCheck (2);
	  break;
	case 'D':
	  // setup impedance check -2ch

	  HWSERIAL.print ("ddddddddddddddd");
	  HWSERIAL.print ("\r");
	  //   Serial.println( "ddddddddddddddd" );
	  impedanceCheck (3);
	  break;
	case 'E':
	  // setup impedance check OFF

	  HWSERIAL.print ("eeeeeeeeeeeeeee");
	  HWSERIAL.print ("\r");
	  //   Serial.println( "eeeeeeeeeeeeeee" );
	  impedanceCheck (4);
	  break;
	case 'F':
	  // testOSC 10Hz -> 12

	  sine1.frequency (12);

	  HWSERIAL.print ("fffffffffffffff");
	  HWSERIAL.print ("\r");
	  //   Serial.println( "fffffffffffffff" );
	  setupInput (InputX);
	  break;
	case 'G':
	  // testOSC 30Hz -> 28

	  sine1.frequency (28);

	  HWSERIAL.print ("ggggggggggggggg");
	  HWSERIAL.print ("\r");
	  //   Serial.println( "ggggggggggggggg" );
	  setupInput (InputX);
	  break;
	case 'H':

	  // testOSC 100Hz  -> 111

	  sine1.frequency (111);

	  HWSERIAL.print ("hhhhhhhhhhhhhhh");
	  HWSERIAL.print ("\r");
	  //   Serial.println( "hhhhhhhhhhhhhhh" );
	  setupInput (InputX);
	  break;
	case 'J':
	  // power 0.1
	  sineP = 0.1;
	  sine1.amplitude (sineP);	// max 1

	  HWSERIAL.print ("jjjjjjjjjjjjjjj");
	  HWSERIAL.print ("\r");
	  //   Serial.println( "jjjjjjjjjjjjjjj" );
	  setupInput (InputX);
	  break;
	case 'K':
	  // power 1.0
	  sineP = 1.0;
	  sine1.amplitude (sineP);	// max 1

	  HWSERIAL.print ("kkkkkkkkkkkkkkk");
	  HWSERIAL.print ("\r");
	  //   Serial.println( "kkkkkkkkkkkkkkk" );
	  setupInput (InputX);
	  break;
	case 'Y':
	  Nchannel = 4;		// set 4 channel mode
	  setupSampleF (1);

	  HWSERIAL.print ("yyyyyyyyyyyyyyy");
	  HWSERIAL.print ("\r");
	  //   Serial.println( "yyyyyyyyyyyyyyy" );
	  setupInput (InputX);
	  break;
	case 'X':
	  Nchannel = 2;		// set 2 channel mode, 500Hz
	  setupSampleF (1);
	  HWSERIAL.print ("xxxxxxxxxxxxxxx");
	  HWSERIAL.print ("\r");
	  //   Serial.println( "xxxxxxxxxxxxxxx" );
	  setupInput (InputX);
	  break;
	case 'U':
	  Nchannel = 2;		// set 2 channel mode, 250HZ, Y is 4 channel mode, X is 2 channel mode
	  setupSampleF (0);
	  HWSERIAL.print ("uuuuuuuuuuuuuuu");
	  HWSERIAL.print ("\r");
	  //   Serial.println( "uuuuuuuuuuuuuuu" );
	  setupInput (InputX);
	  break;

	default:
	  nothings = 0;
	}

      stringComplete = false;

    }

}

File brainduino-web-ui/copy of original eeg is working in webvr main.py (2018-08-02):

import argparse
import asyncio
import http.server
import os
import socketserver

import serial
import websockets


def offsetBinaryToInt(hexstr, offset):
    if len(hexstr) != 6:
        return -1
    not_encoded = int(hexstr, 16)  # Make a python integer out of the hex string
    if not_encoded & 1 << offset:  # Test if the most significant bit is on == this is a positive number
        encoded = not_encoded & ~(1 << offset)
    else:
        encoded = not_encoded - 2**offset
    return encoded


def adc2volts(i):
    return i * 5 / 2**23


def findPath():
    if args.path:
        return args.path
    basepath = "/dev/rfcomm"
    for i in range(5):
        testpath = basepath + str(i)
        if os.path.exists(testpath):
            return testpath


async def brains(websocket, path):
    """
    Example Brainduino serial stream:

    F80F19\t7801F4\rF80F19\t7801F4\rF80F19\t7801F4\r
    """
    print("brains")
    channels = (bytearray(6), bytearray(6))
    ctr = 0
    while True:
        bs = s.read(64)
        for b in bs:
            if b == ord('\r'):
                try:
                    c1, c2 = offsetBinaryToInt(channels[0], 23), offsetBinaryToInt(channels[1], 23)
                    c1, c2 = adc2volts(c1), adc2volts(c2)
                    await websocket.send("%s %s" % (c1, c2))
                except Exception:
                    await websocket.send("%s %s" % channels)
                ctr = 0
            elif b == ord('\t'):
                continue
            elif ctr < 6:
                channels[0][ctr] = b
                ctr += 1
            elif ctr >= 6:
                channels[1][ctr % 6] = b
                ctr += 1


async def httpd():
    handler = http.server.SimpleHTTPRequestHandler
    port = 8080
    httpd = socketserver.TCPServer(('127.0.0.1', port), handler)
    print("serving at port", port)
    # await httpd.serve_forever()


def main():
    start_server = websockets.serve(brains, '127.0.0.1', 5678)

    asyncio.get_event_loop().run_until_complete(start_server)
    # asyncio.get_event_loop().run_until_complete(httpd())

    asyncio.get_event_loop().run_forever()


if __name__ == '__main__':
    parser = argparse.ArgumentParser()
    parser.add_argument("--path", help="path to the brainduino device")
    args = parser.parse_args()
    brainduino_path = findPath()
    s = serial.Serial(brainduino_path, baudrate=230400)
    if s.isOpen():
        print("Connected to brainduino at path=[%s]" % brainduino_path)
        s.write(bytes("S", "utf-8"))
        s.write(bytes("U", "utf-8"))
        main()
    else:
        print("Failed to connect to brainduino. Exiting now.")

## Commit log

2018-07-26 sync local changes + python code for brain data over web sockets
2018-07-29 improve path finding to brainduino device
2018-09-20 Merging repos
    [AD7173.brd, AD7173.sch, BaseShieldBrainDuino24Nov2017.brd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]
2018-09-24 Refactor with go-broadcast in Device
2018-09-27 Refactor Device into a Subscriber
2018-10-04 autoscale y-axis for timeseries charts

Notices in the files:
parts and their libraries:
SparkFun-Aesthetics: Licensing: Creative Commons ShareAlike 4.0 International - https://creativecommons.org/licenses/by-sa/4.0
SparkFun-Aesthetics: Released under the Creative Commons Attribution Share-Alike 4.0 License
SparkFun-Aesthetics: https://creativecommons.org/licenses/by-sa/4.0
